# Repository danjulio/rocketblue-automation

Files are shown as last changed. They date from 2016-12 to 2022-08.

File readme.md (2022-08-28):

## Rocket Blue Automation

This directory contains information for Rocket Blue Automation projects.

### Solar Pi Platter

The [Solar Pi Platter](https://www.danjuliodesigns.com/products/solar_pi_platter.html) is a sophisticated expansion board for the Raspberry Pi Zero and Pi Zero 2 W single-board computers first introduced on [kickstarter](https://www.kickstarter.com/projects/1647124460/solar-pi-platter) in 2016.

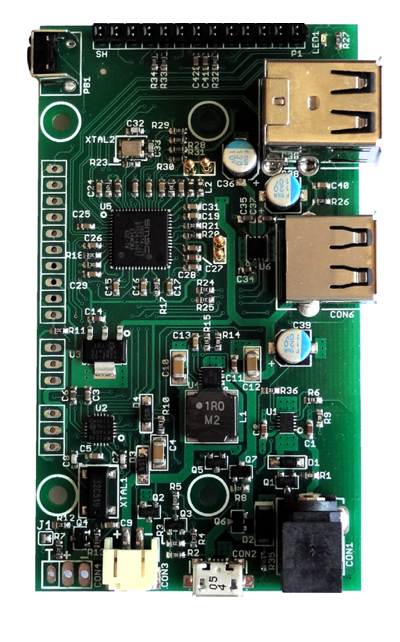
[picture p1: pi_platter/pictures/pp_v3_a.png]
Solar Pi Platter


The board can be purchased on [tindie] (https://www.tindie.com/products/globoy/solar-pi-platter/).

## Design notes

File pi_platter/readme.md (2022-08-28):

## Documentation

This directory contains supporting material for the [Solar Pi Platter](https://www.danjuliodesigns.com/products/solar_pi_platter.html) including documentation, utility software and example projects.

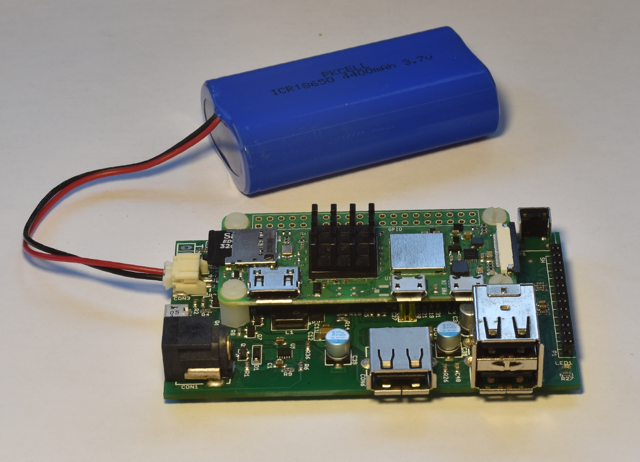
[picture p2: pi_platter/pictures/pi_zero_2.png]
Pi Zero 2 W


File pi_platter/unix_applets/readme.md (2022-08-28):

## Documentation

This directory contains Raspbian utility software for the Solar Pi Platter.

### talkpp
talkpp is a utility program to simplify communicating with the Solar Pi Platter.  It provides a simple command-line interface to allow the user to directly (or via scripts) send commands to the board and to easily manage the Real Time Clock.  

Starting with version 0.5 it can communicate with the Solar Pi Platter via either the pseudo-tty /dev/pi-platter if the ppd daemon is running or the actual hardware serial device associated with the board if ppd is not running.  It uses udev to automatically find the correct serial device for the board, independent of other USB serial devices.

Both the source and a binary compiled under Raspbian Jessie are included.  The binary can simply be downloaded and installed in /usr/local/bin.  The source is easily compiled in the directory containing the source file.

    sudo apt-get update
    sudo apt-get install libudev-dev
    gcc -o talkpp talkpp.c -ludev
    sudo mv talkpp /usr/local/bin

talkpp takes the following arguments:

    talkpp [-c <command string>]

          [-s] [-t] [-f]

          [-a <alarm timespec>] [-d <delta seconds>] [-w]

          [-u | -h]

    -c <command string> : send the command string.  Command strings without an "=" character cause the utility to echo back a response.

    -s : Set the Device RTC with the current system clock
 
    -t : Get the time from the Device RTC and display it in a form useful to pass to "date" to set the system clock ("+%m%d%H%M%Y.%S")

    -f : Get the time from the Device RTC and display it in a readable form.

    -a <alarm timespec> : Set the Device wakeup value (does not enable the alarm).  <alarm timespec> is the alarm time in date time format ("+%m%d%H%M%Y.%S")

    -d <delta seconds> : Set the Device wakeup to <delta seconds> past the current Device RTC time value (does not enable the alarm)

    -w : Display the wakeup value in a readable form.

    -u, -h : Usage (and optional help)

Example command to Solar Pi Platter: `talkpp -c B`

Setting the Solar Pi Platter RTC from the Pi's RTC: `talkpp -s`

Setting the Pi's RTC from the Solar Pi Platter (using BASH): `sudo date $(talkpp -t)`

talkpp will echo responses from the Solar Pi Platter to stdout.  It will also echo the last warnings or error messages that has been sent.

### ppd
ppd is a daemon for the Solar Pi Platter.  It provides two main functions.  It will execute a controlled shutdown if the Solar Pi Platter detects a critical battery voltage (and will power-down the entire system after [default] 30 seconds).  Since it opens the serial port associated with the Solar Pi Platter it also provides one or two mechanisms for other applications to communicate with the Solar Pi Platter.  It creates a pseudo-tty device named /dev/pi-platter which can be used just like the hardware serial port.  It also, optionally, can create a TCP port for applications like telnet to connect to.  

It is important that software not open the hardware serial port, /dev/ttyACM<n>, when ppd is running since it is using the port.

ppd takes the following command line arguments:

    -d : Run as a daemon program (disconnecting from normal IO, etc).  ppd can be run as a traditional process without this argument.

    -p netport : Enable a TCP socket connection on the specified port.  This is required to enable socket communication with ppd.  Exclude this line to only enable /dev/pi-platter as a mechanism to communicate with the Solar Pi Platter.

    -m max-connections : Specify the maximum number of socket connections that can be made to the port specified with -p.  The default is 1.

    -o seconds : Configure Pi Platter to shut off power after the specified period upon receipt of SIGTERM.

    -r : Enable auto-restart on charge (set the Pi Platter "C7=1") after critical battery shutdown.

    -x debuglevel : Set the debug level (ppd uses the system logging facility.  0 is default (only log start-up).  Values of 1 - 3 include progressively more information.

    -h : Display usage and command line options.

There are many ways to start a daemon, for example a configuration file in / or a script in /etc/init.d.  A very easy way to start it is to include it in /etc/rc.local.  For example, add the following before the "exit 0" at the end of /etc/rc.local (assuming you have placed the ppd executable in /usr/local/bin).

    # Start the Pi Platter Daemon
    /usr/local/bin/ppd -p 23000 -r -d &

This starts ppd with socket communication available on port 23000 and auto-restart in the event of a critical battery shutdown.

Both the source and a binary compiled under Raspbian Jessie are included.  The binary can simply be downloaded and installed in /usr/local/bin.  The source is easily compiled in the directory containing the source file.

    sudo apt-get update
    sudo apt-get install libudev-dev
    gcc -o ppd ppd.c -ludev
    sudo mv ppd /usr/local/bin

### pp\_power\_mon
pp\_power\_mon is a Desktop widget designed to display the Solar Pi Platter voltage and charge status as well as provide control over the two switchable USB ports.

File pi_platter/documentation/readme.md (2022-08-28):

## Documentation

This directory contains documentation for the Solar Pi Platter.

1. instructions\_v1_0.pdf - A quick summary of board operation, command set and configuration items.
2. solar\_pi_platter.pdf - The User Manual.
3. solar\_pi\_platter_schem.pdf - The board schematic.
4. USB\_expansion_example.png - An image showing how to use the board with a computer other than the Raspberry Pi Zero using a USB cable to supply both power and data.

### Questions?

Contact the author - dan@danjuliodesigns.com

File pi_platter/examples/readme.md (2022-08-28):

## Examples

 1. Porta-Pi - Using the Pi Platter, along with a high resolution 1024x600 pixel HDMI monitor to build a touchscreen computer with soft power off.
 2. motioneyeos - Using the Pi Platter to provide battery backup and pan/tilt functionality to the motioneyeos distribution.
 3. pi_car - The original demo created during development of the Pi Platter using it to provide power and motor control to a wifi-controlled robotic car with vision.
 4. solar_timelapse - A solar powered timelapse camera using the solar charging capability of the Pi Platter along with RTC-controlled wake-up for a raspberry pi camera.

 The ```nature_cam.sh``` script is a simple demonstration script that can be included in a camera like the solar_timelapse along with a servo to take pictures in multiple directions.
 
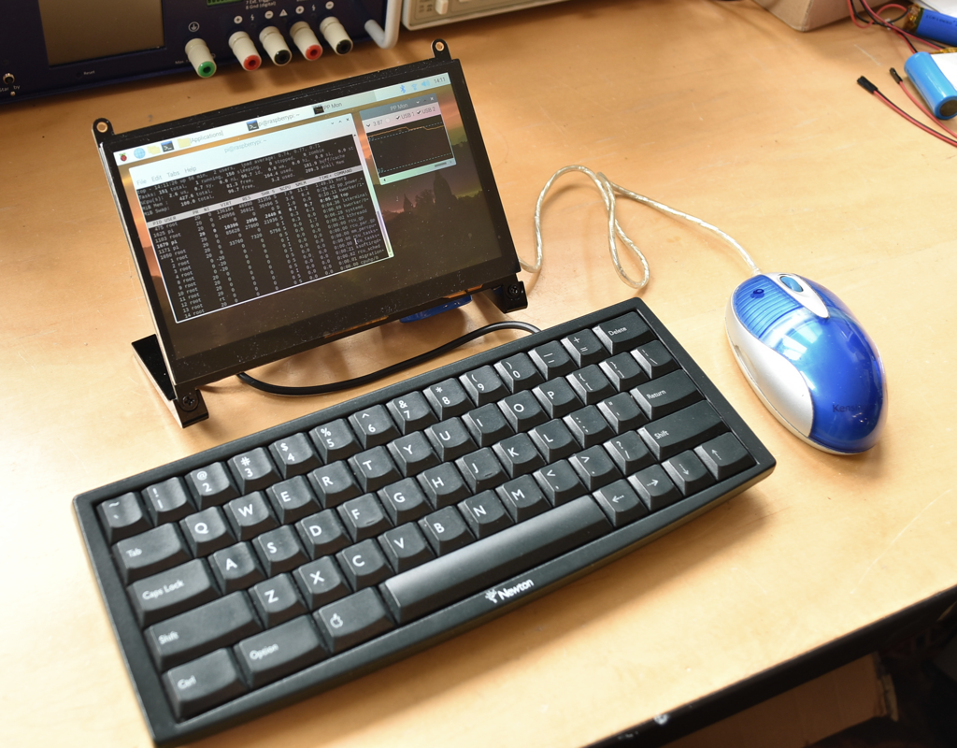
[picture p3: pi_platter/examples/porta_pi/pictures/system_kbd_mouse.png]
Porta-Pi

 
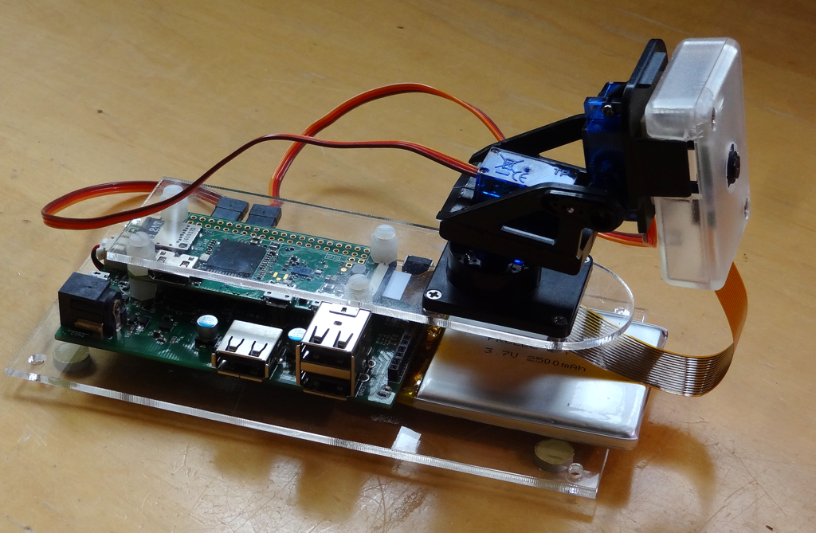
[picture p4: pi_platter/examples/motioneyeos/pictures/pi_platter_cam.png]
Motioneyeos camera


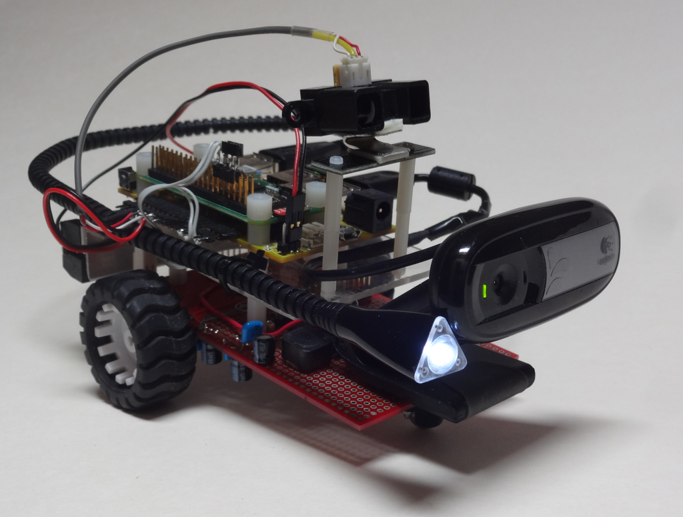
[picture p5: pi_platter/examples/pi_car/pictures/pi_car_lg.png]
Pi Car


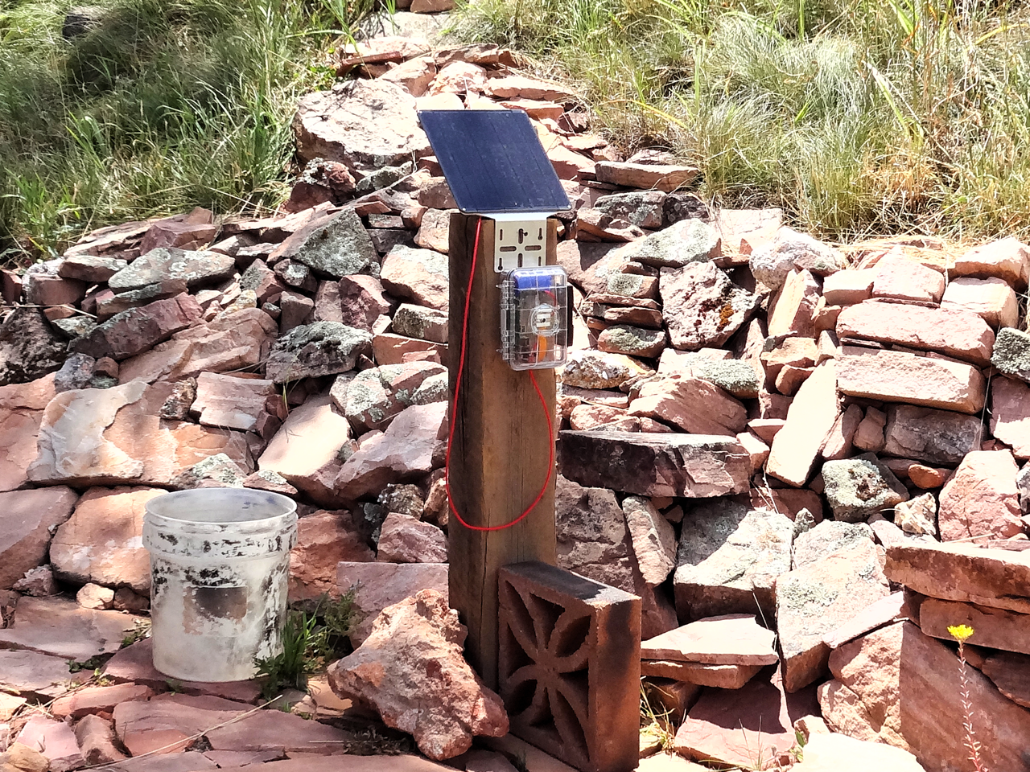
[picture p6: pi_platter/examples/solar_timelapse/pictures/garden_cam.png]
Timelapse Camera


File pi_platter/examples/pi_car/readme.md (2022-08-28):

## Documentation

This directory contains the components used for the Pi Car designed as an example during the kickstarter campaign.  It probably can't be used as-is but may give some ideas.

Pi Car

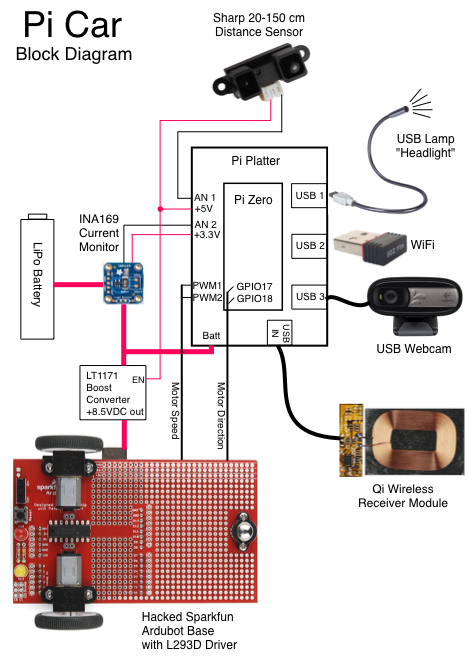
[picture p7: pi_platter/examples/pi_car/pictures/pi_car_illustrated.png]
Pi Car Block Diagram


### Motor Control

The Pi Car was built on an old Sparkfun Ardubot base.  The Ardubot was designed to be controlled by an Arduino with only forward/reverse control at a fixed speed but contained a prototyping area.  It used a L293D driver with the Enable input tied high.  I modified the board so the Solar Pi Platter PWM signals drove the Enable input for speed control.  A pair of NPN transistor inverters allowed Pi GPIO signals to control motor direction.  The high PWM frequency is used for smooth motor control.

A LT1171 boost converter was used to step up the battery voltage to approximately 8.5 volts to provide power for the motors.

### Video

A Logitech USB camera coupled with mjpg-streamer handled up to 15 fps at 320x240 pixels for reasonable video streaming.  mjpg-streamer setup is not described here but is fairly straight forward.

A Sharp distance sensor was mounted above the camera and connected to a Solar Pi Platter analog input with Vref set to 4.096 volts.  A table in the control software maps the ADC value to distance.

### Other peripherals

A USB reading lamp made the perfect steampunk headlight and can be turned on and off using the Pi Platter’s per-port USB power switching.

An inexpensive INA169-based current sensor in series between the battery and the rest of the system and wired to the Pi Platter’s other analog input gives current draw.  The Pi Car idles at around 700 mA from a charged battery and can pull upwards of 1500-2000 mA when the motors are running and loaded.

Finally a Qi receiver module connects to the Pi Platter’s USB power input for wireless charging.

### Joystick control

An old analog joystick (2 10-kohm pots and a button) was connected to an Arduino Leonardo (DF Robot beetle) running a simple sketch that reported joystick and button information over a USB Serial link.

### Software

There are three software components.

1. pi\_car.c - This is the software running on the Raspberry Pi.  It uses a single TCP port for communication with the control software running on the control computer.  It requires [WiringPi](http://wiringpi.com/) to be installed (for access to the GPIO pins).
2. pi\_car\_tv - A [Xojo](https://www.xojo.com/) project that implements the main control program.  This project may be compiled for Windows, Mac OS X or Linux.  Xojo is a commercial product which requires a paid license to build a binary executable but the project can be compiled and run from within the IDE without any license.  Builds for several platforms are found here.
3. read\_joystick.ino - The arduino sketch reading the joystick.  Should be put in a folder called read\_joystick.

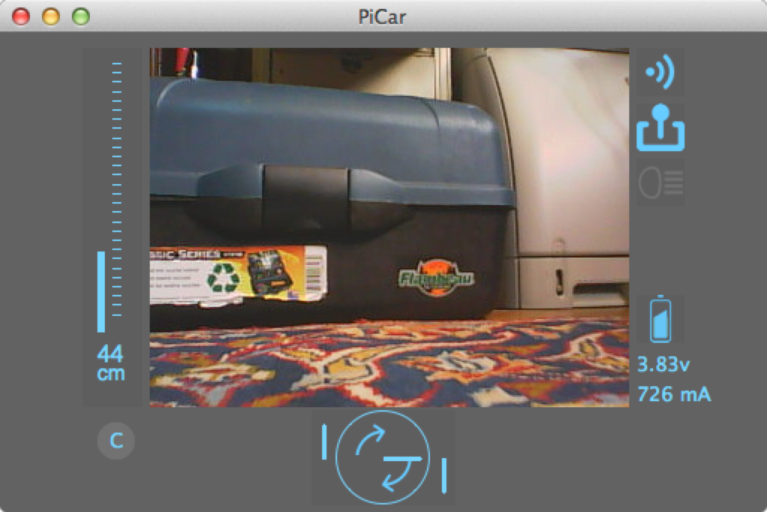
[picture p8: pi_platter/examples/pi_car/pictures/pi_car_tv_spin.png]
Pi Car Video


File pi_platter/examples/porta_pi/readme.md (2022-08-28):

## Porta-Pi
This directory contains the design for a 3D-printed baseplate and instructions for assembling a portable touchscreen based computer using the Raspberry Pi Zero 2 W that has higher resolution than the official 7" Pi LCD screen.  The Solar Pi Platter is used to provide power management, including soft power control, charging and switched USB expansion ports.  Features include

- 7" 1024x600 pixel capacitive touch LCD screen
- Stereo sound with built in speakers
- USB powered with 4400 mAHr battery for portable use
- Two power-switched USB ports
- Auto power-off after software shutdown using ```ppd``` utility.

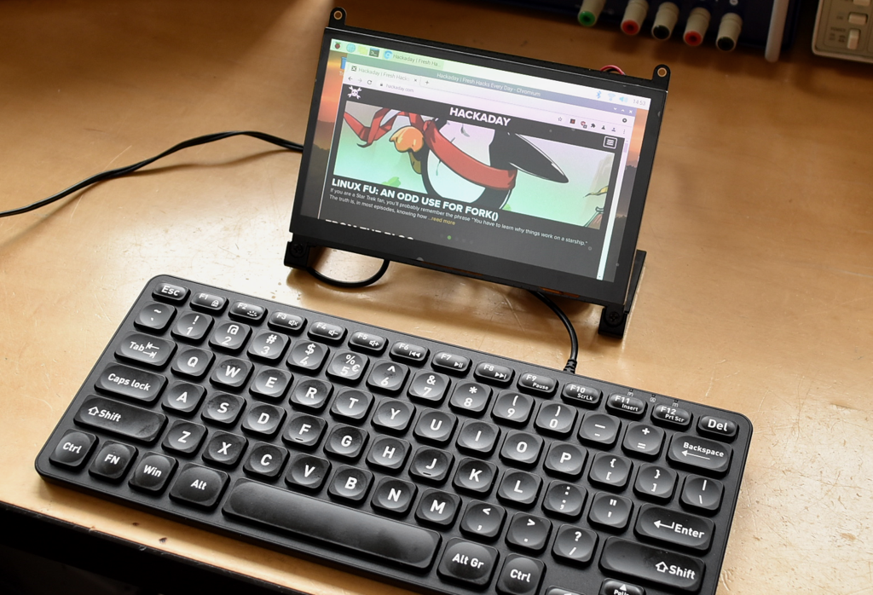
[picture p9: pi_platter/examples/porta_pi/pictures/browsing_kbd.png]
Browsing


### Parts

1. Solar Pi Platter ([tindie link] (https://www.tindie.com/products/globoy/solar-pi-platter/))
2. Raspberry Pi Zero 2 W
3. Norsmic 7" HDMI monitor ([Amazon link](https://www.amazon.com/gp/product/B09KB7XKB2))
4. 4400 mA 3.7V Li-Ion battery ([Adafruit link](https://www.adafruit.com/product/354)).  Be sure to use a battery with the Adafruit/Sparkfun style polarity 2mm JST connector.
5. Full-size to mini HDMI adapter (get the smallest adapter - not cable - you can find).
6. 4 4-40 3/8" nylon stand-offs (the same stand-offs that come with the Solar Pi Platter).
7. 2 165x2.5mm (6.5x0.1") zip ties.
8. 3D printed base plate (using STL files found here).

In case the Amazon link no longer works, look for a monitor like the following.  You will use the short USB cable and flex circuit HDMI cable.  The included Power Adapter and MicroUSB cable can be used to power the Porta-Pi.

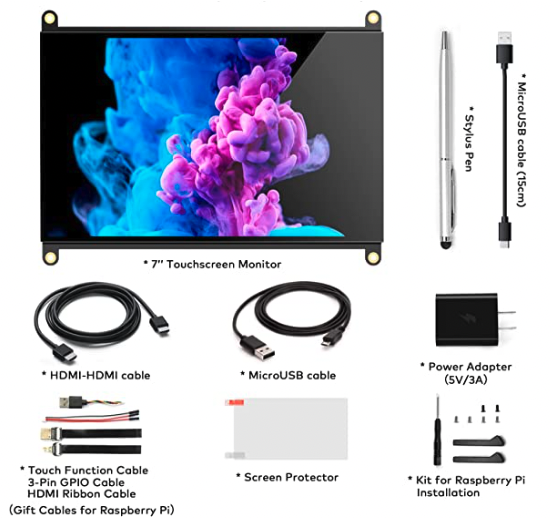
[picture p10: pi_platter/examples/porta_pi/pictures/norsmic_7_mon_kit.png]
Norsmic 7" Monitor


### Assembly
#### Base Plate
Slice and 3D print the ```mount_plate.stl``` file from the ```baseplate``` directory here.

Install the four extra stand-offs using the nuts from the Solar Pi Platter and the two zip ties (don't close them fully yet).

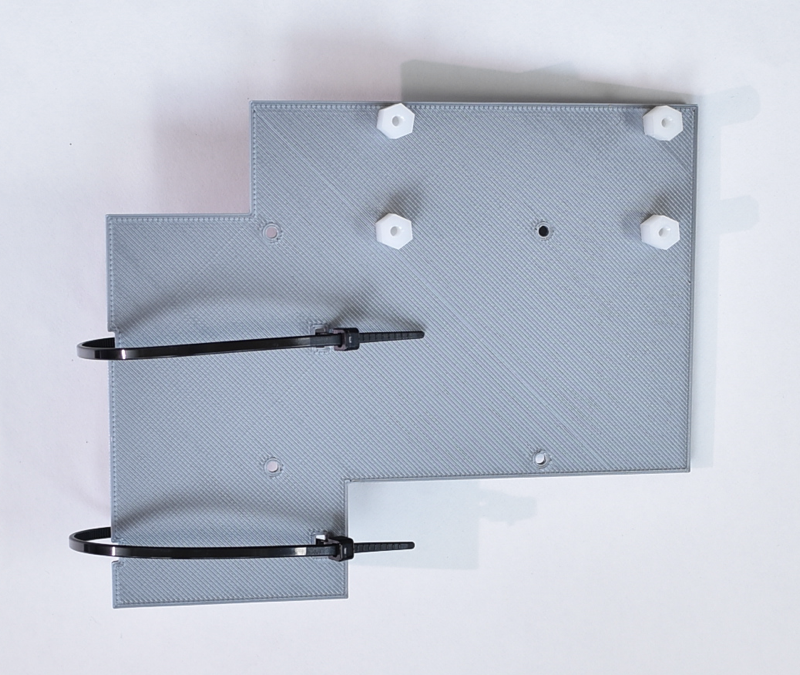
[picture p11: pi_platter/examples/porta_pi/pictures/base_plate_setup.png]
Base Plate Setup


#### Add USB and HDMI cables to LCD module
The Norsmic LCD screen comes with several cables including a short USB cable and a short flat HDMI cable.  Connect those to the monitor as shown below.  I used some tape to ensure the flat cable was secure.

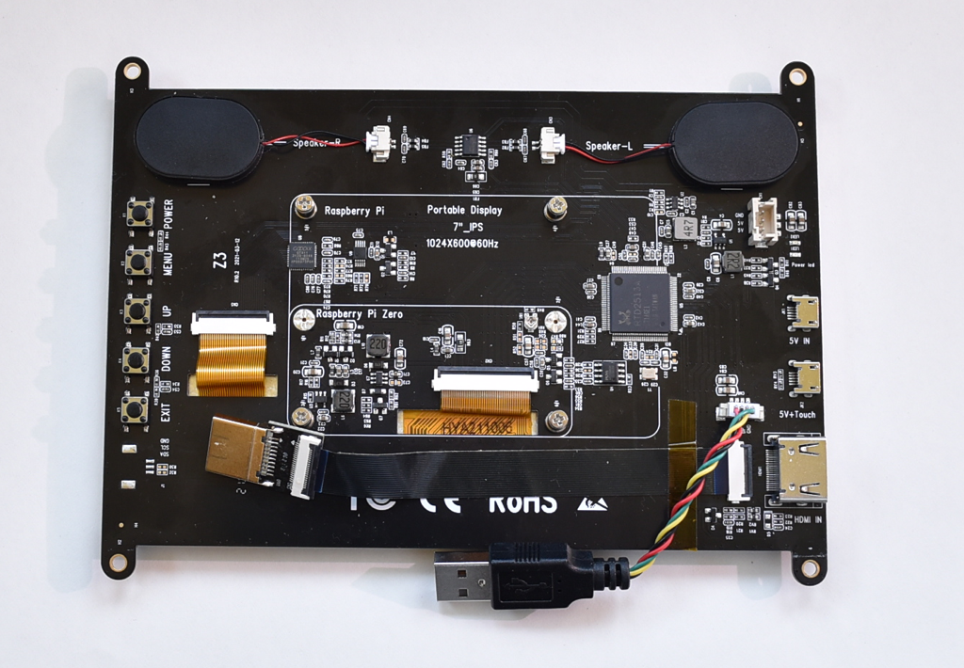
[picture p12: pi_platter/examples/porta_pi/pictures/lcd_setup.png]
LCD Screen Setup


#### Mount Base Plate
Attach the assembled Base Plate to the Raspberry Pi standoffs on the back of the monitor using the four metal screws that came with it.

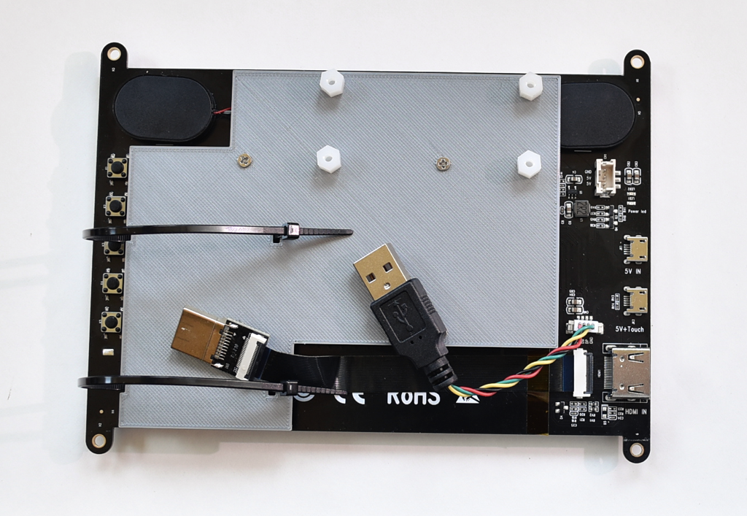
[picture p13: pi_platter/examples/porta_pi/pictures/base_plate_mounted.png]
Mounted Base Plate


#### Mount the Pi Platter and Battery
Attach the Pi Platter to the Base Plate using the four stand-offs that came with it.   Plug the USB cable into the single (un-switched Pi Platter USB port).  Also mount the battery to the Base Plate as shown below and tighten the zip ties to hold it in place.  Cut off the extra zip tie material.

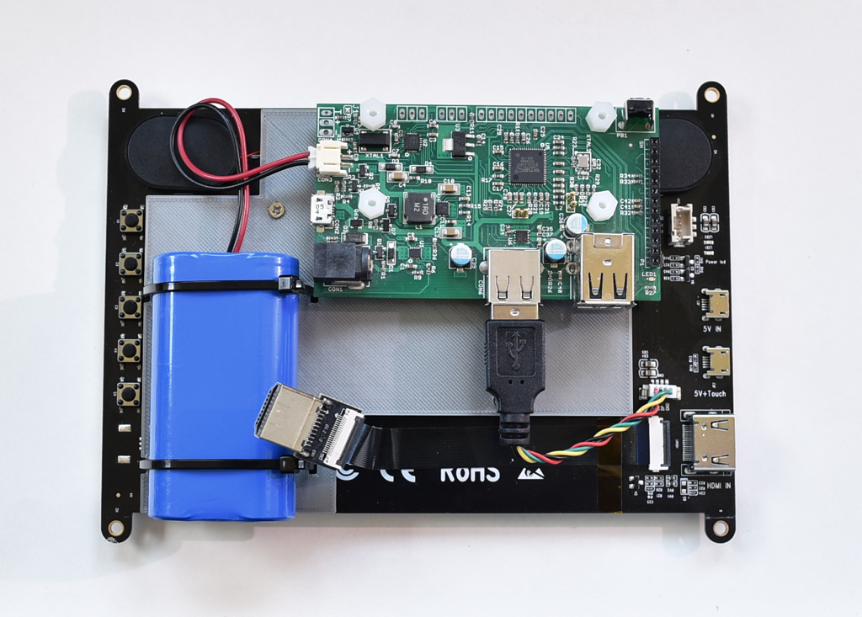
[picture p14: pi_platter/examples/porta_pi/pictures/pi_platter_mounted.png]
Mounted Pi Platter


#### Mount the Raspberry Pi Zero 2 W

Attach the Pi Zero to the Pi Platter using the four nylon screws that came with the Pi Platter.  Plug the HDMI cable into the Pi's mini-HDMI port using the HDMI to Mini HDMI adapter plug.

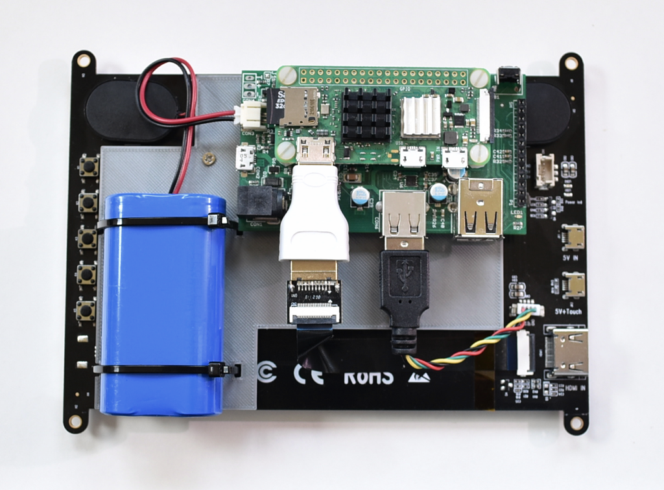
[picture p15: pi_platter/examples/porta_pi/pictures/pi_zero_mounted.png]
Mounted Pi


Congratulations, the hardware is assembled.  You can use the mounted provided in the monitor kit or you can assembled the completed unit into your own enclosure using the screw mounts on the top and bottom of the monitor PCB.

#### Note about power
The ideal power source for this system is a 2.5A 5.1V Micro-USB power supply such as the official Raspberry Pi supply.  The slightly higher supply voltage allows the Pi Platter to both power the system and charge the battery with its maximum 750 mA charge rate.

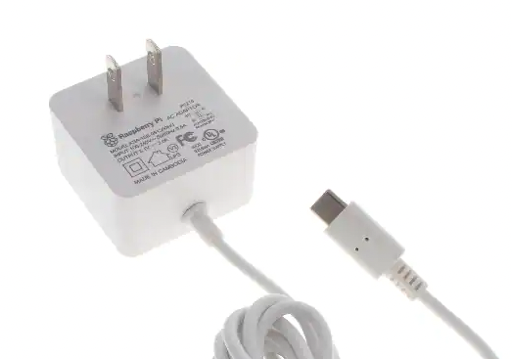
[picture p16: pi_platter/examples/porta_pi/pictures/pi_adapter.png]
Official Pi Adapter


The adapter supplied by Norsmic or other adapters with > 2.5A can also be used.

WARNING: Only plug the USB cable into the Pi Platter Micro-USB port.  Do not connect anything to either Pi Micro-USB ports.  Doing so may damage the Pi Platter.

You can even use the solar panel input on the Pi Platter to charge the system from sunlight.  However that input won't be able to keep both the battery charged and system powered so it would be most useful in a situation where you charge the system using solar power and then run it for a while from the battery.

### Software Setup
#### Load Raspbian
Load a 32-bit Raspbian distribution onto a Micro-SD card and install it in the Raspberry Pi.  Power the Pi Platter with the USB adapter.  Turn the system on by pressing the Pi Platter power button.  You will see the green light turn on the Pi Platter followed by the Raspberry Pi booting.

#### Load and configure the Pi Platter utilities
Install the ```ppd``` utility program (found in this repository or from my website), for example in ```/usr/local/bin```.  Add the following line  to the ```/etc/rc.local``` file.

	/usr/local/bin/ppd -p 23000 -o 30 -r -d &

This will configure the utility as a daemon that watches for the SIGTERM signal and uses that to power off the system 30 seconds later.  This signal is sent when you select shutdown from the GUI or execute ```shutdown now``` from the command line.

You may also install ```ppp_power_mon``` to add a desktop widget displaying the current battery level and charge status, as well as providing controls to switch on and off the other two USB ports on the Pi Platter.

### Operation
Switch the system on by pressing the power button on the Pi Platter.

Switch the system off by selecting ```Logoff->Shutdown``` from the Start Menu or typing ```sudo shutdown now``` in a terminal.

The monitor should automatically power on when the Pi video starts.  You use the buttons on the monitor PCB to control brightness and volume.

### Questions?

Contact the author - dan@danjuliodesigns.com

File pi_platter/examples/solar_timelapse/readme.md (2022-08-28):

## Documentation

This directory contains the script for the solar powered time-lapse camera documented at [my website](https://www.danjuliodesigns.com/products/pi_platter_timelapse.html).

The script controls taking a picture, scheduling the next wake-up time for the system and then executing a controlled shutdown and power-down.

It also monitors a switch attached to the Solar Pi Platter A1 input to allow the user to power-up the system without the time-lapse camera functionality (for example, to off-load photos).

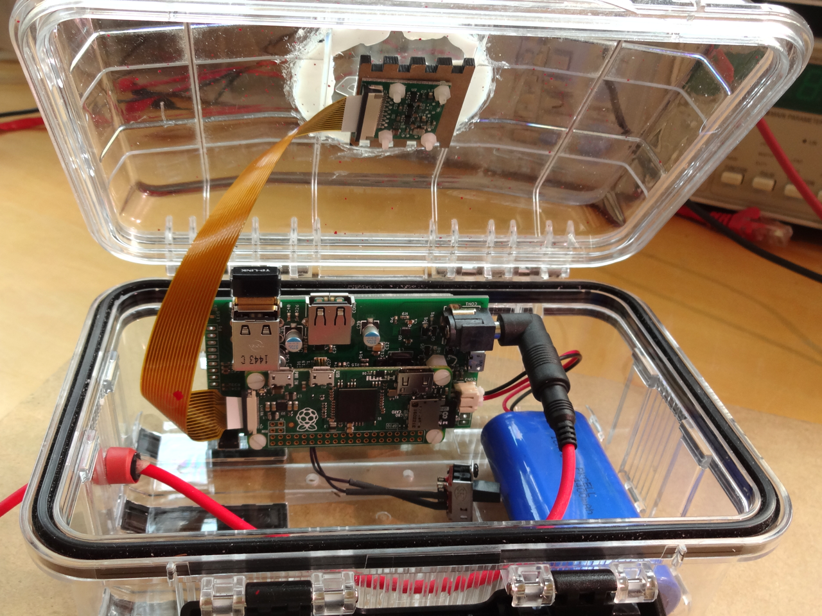
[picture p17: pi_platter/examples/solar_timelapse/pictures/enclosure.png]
Timelapse Camera


### Configuration

Install and configure an operating system.  I use [DietPi](http://dietpi.com).  Install any necessary additional software such as ssh and configure WiFi if desired.

Install talkpp and the powerdown script in /usr/local/bin.

Install the timelapse.sh script in /usr/local/bin.

Create the picture repository at /usr/local/pictures: sudo mkdir /usr/local/pictures.

Edit /etc/rc.local and add the lines

	# Start the photography script
	/usr/local/bin/timelapse.sh &

Set the Solar Pi Platter RTC from the Pi (after it's clock as been set) using the command

	talkpp -s

### Hardware

A switch with a 10k-ohm pull-up resistor is connected to the Pi Platter A1 input.  The pull-up is connected between A1 and 3.3V so that A1 is high when the switch is open. The switch is connected between A1 and GND so that A1 is low when the switch is closed.

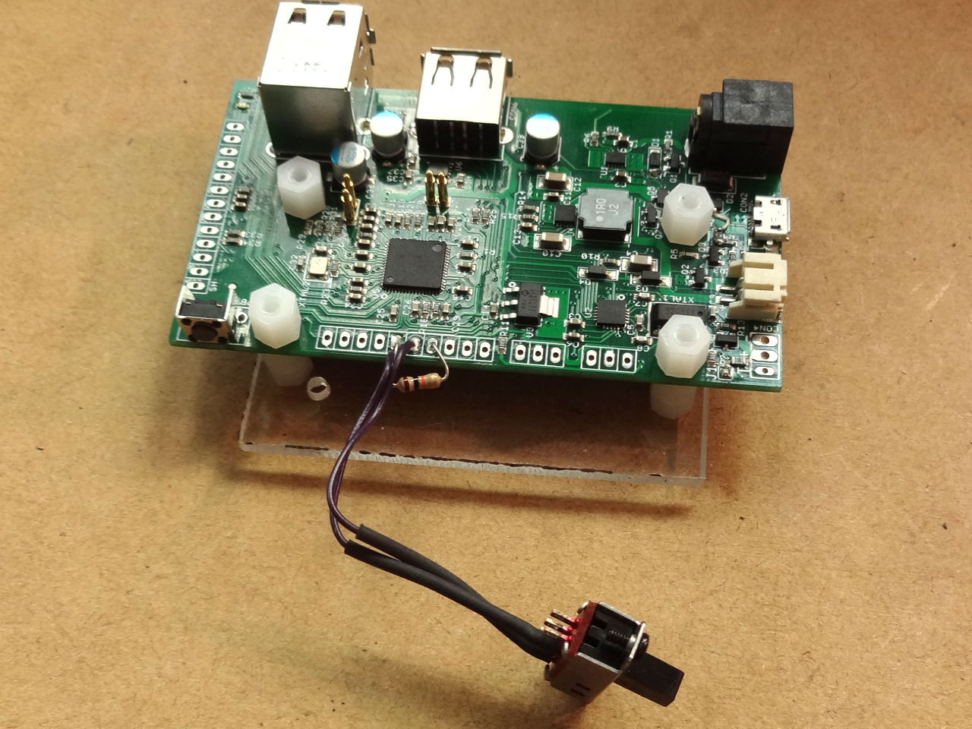
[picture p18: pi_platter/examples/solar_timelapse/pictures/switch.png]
Switch Wiring


Power is supplied using a 6V 9W solar panel such as this one from [voltaic](https://voltaicsystems.com/9-watt-panel/).

### Operation

Open the switch and power-up the Pi Platter.  It will take the first photograph, schedule the next photograph and then power down.

Close the switch before powering up to configure the device into offload mode.

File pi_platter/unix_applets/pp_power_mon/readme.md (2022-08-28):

## pp\_power\_mon

This directory contains the code for the pp\_power\_mon GUI program.  This utility displays the Pi Platter battery voltage and charge status and allows control of the switchable USB port power in a little applet in a small window on the Raspberry Pi desktop.

The utility is written using the [Xojo](https://www.xojo.com) development environment and compiled for 32-bit ARM 7 linux (such as found on the Raspberry Pi Zero 2 W but not the original Raspberry Pi Zero).  It should run on other ARM 7 linux computers with hardware floating point support.  Both the Xojo source and compiled binary are found here.

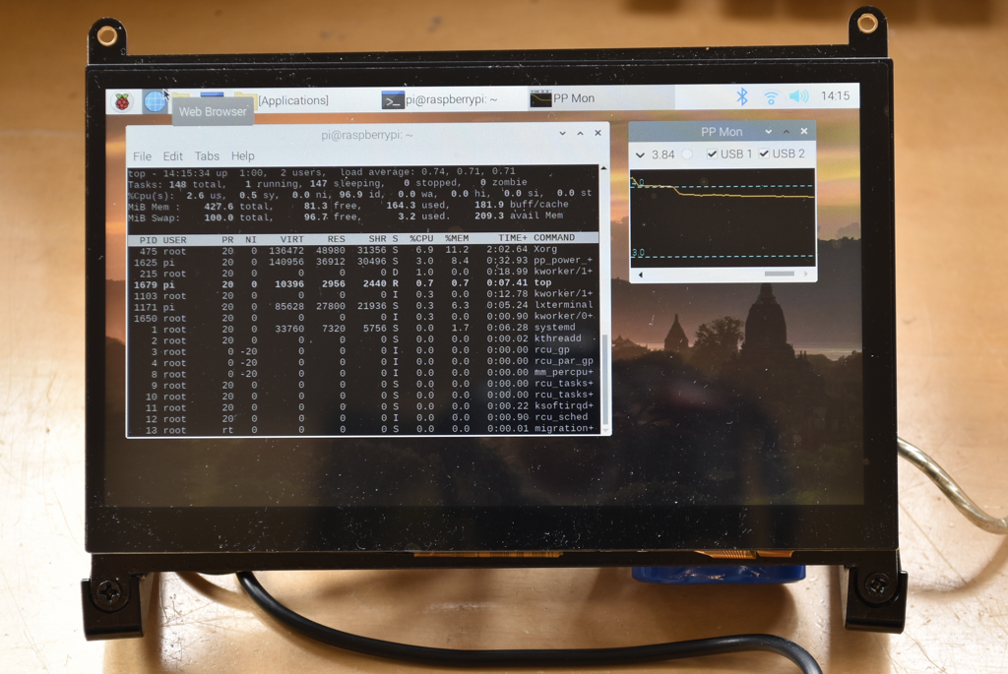
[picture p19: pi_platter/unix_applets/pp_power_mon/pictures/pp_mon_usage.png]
Utility on Desktop


### Installation
Copy the ```ppp_power_mon.zip``` file found at the following locations to your Pi.

1. In this repository in the ```xojo/Builds - pp_power_mon/Linux ARM/``` directory
2. From the download section on the Solar Pi Platter page at my [website](https://www.danjuliodesigns.com/products/solar_pi_platter.html).

Unzip in a known location such as Applications in the Pi user's home directory.

	unzip ppp_power_mon.zip
	
The executable ```ppp_power_mon```, along with supporting libraries, will be found in the unpacked directory.

	pi@raspberrypi:~/Applications $ ls pp_power_mon/
	pp_power_mon  'pp_power_mon Libs'  'pp_power_mon Resources'

Ensure the binary is executable.

	pi@raspberrypi:~/Applications $ chmod +x pp_power_mon/pp_power_mon

### Running and Operation

Execute the utility from a shell that has the desktop environment configured (e.g. a terminal window).

	pi@raspberrypi:~/Applications $ ./pp_power_mon/pp_power_mon &

The utility should start in a condensed format showing the battery voltage, charge status and USB power controls.

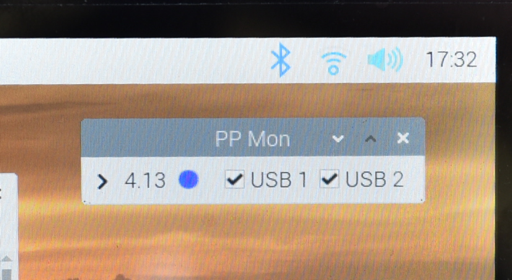
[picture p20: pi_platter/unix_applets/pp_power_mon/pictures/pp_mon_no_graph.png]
Condensed Utility


The status indicator to the right of the battery voltage displays the following information via its color.

- Battery Charging : Green
- Battery Low : Red
- Power from USB (not charging) : Blue
- Normal battery operation : White

Clicking the disclosure arrow to the left of the battery voltage displays the battery graph (updated every second).  The following picture shows the battery voltage after charging commenced.

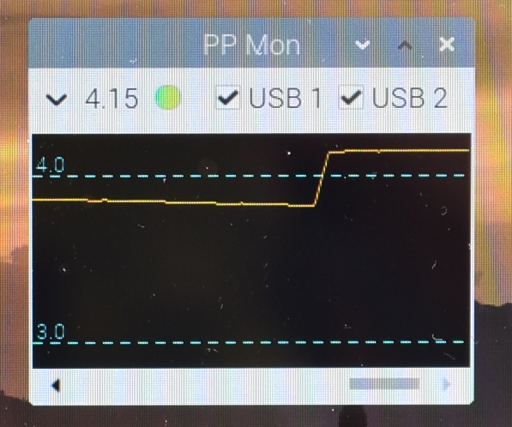
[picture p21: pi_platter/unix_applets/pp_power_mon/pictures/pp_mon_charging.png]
Utility with Graph


The checkboxes are used to turn power on and off to the two switchable USB ports on the Solar Pi Platter.  Just be sure your mouse isn't plugged in to the port you turn off... 

### Note
This program won't run on the original Raspberry Pi Zero or Raspberry Pi Zero W because they lack the hard floating point that the Xojo binary requires.

### Questions?

Contact the author - dan@danjuliodesigns.com

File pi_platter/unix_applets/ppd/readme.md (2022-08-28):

## ppd

This directory contains the code for the ppd daemon.

ppd is a daemon program designed to run on a Raspberry Pi (or other linux computer).  It allows the system to execute a controlled shutdown in the case of a critically low battery voltage (that has triggered the Solar Pi Platter to start a count-down to powering down the entire system).  This is important to protect the Raspberry Pi's SD-card filesystem from corruption that can occur when power is removed from a running system.  It does this by connecting to the hardware serial port associated with the Solar Pi Platter (like talkpp, it uses udev to figure this out) and looks for the WARN string sent the Solar Pi Platter for critical battery detection.  Since it "commandeers" the hardware serial port, it also provides additional mechanisms for user application code to communicate with the Solar Pi Platter.  It always creates the pseudo-tty "/dev/pi-platter" which can be treated like a serial port connection.  It can optionally also create a TCP socket for network communication with the Solar Pi Platter.

It uses udev to be able to idenfity which hardware serial device belongs to the Solar Pi Platter (via the USB VID, PID and product strings).

###Building

A prebuilt binary is included here but building is very easy:

    gcc -o ppd ppd.c -ludev

The compiled binary should be copied to /usr/local/bin.

    sudo mv ppd /usr/local/bin

You may have to set appropriate permissions (you will have to do this if you just copy the
prebuilt binary from git to /usr/local/bin).

    sudo chmod 775 /usr/local/bin/ppd

libudev-dev must be installed:

    sudo apt-get update
    sudo apt-get install libudev-dev

###Usage

ppd should be started as a daemon at start-up.  The easiest way to do this is to include somethine like the following in /etc/rc.local.

    # Start the Pi Platter Daemon
    /usr/local/bin/ppd -p 23000 -r -d &

It is also possible to create a conf file in /etc/init or a startup script in /etc/init.d.

####Command line options

ppd takes the following command line arguments:

    -d : Run as a daemon program (disconnecting from normal IO, etc).  ppd can be run as a traditional process without this argument.

    -p netport : Enable a TCP socket connection on the specified port.  This is required to enable socket communication with ppd.  Exclude this line to only enable /dev/pi-platter as a mechanism to communicate with the Solar Pi Platter.

    -m max-connections : Specify the maximum number of socket connections that can be made to the port specified with -p.  The default is 1.
    
    -o seconds : Configure Pi Platter to shut off power after the specified period upon receipt of SIGTERM.

    -r : Enable auto-restart on charge (set the Pi Platter "C7=1") after critical battery shutdown.

    -x debuglevel : Set the debug level (ppd uses the system logging facility.  0 is default (only log start-up).  Values of 1 - 3 include progressively more information.

    -h : Display usage and command line options.

####telnet example

To connect to the TCP socket using telnet from some other computer:

    telnet <Raspberry Pi IP Address> 23000

Which should result in something like (user types "B" and then "S"):

    Trying <Raspberry Pi IP Address>...
    Connected to raspberrypi0.lan.
    Escape character is '^]'.
    B
    B=4.12
    S
    S=20

Note that opening the socket without additional precautions may be a security risk (anybody could telnet to your Pi and shut it down).  That's why ppd makes this an option.

####Soft shutdown
The ```-o``` option (introduced in version 0.2) configures the program to automatically power off the Pi a configurable number of seconds after receiving a SIGTERM signal.  SIGTERM is sent when the Pi has been commanded to shut down (for example using the GUI or ```shutdown``` command).

Start the program as a daemon using this option with an argument of seconds longer than it takes for the Pi to execute a shutdown and the system will power off automatically.

	/usr/local/bin/ppd -p 23000 -o 30 -r -d &

Just be sure to use a SIGKILL to stop the daemon (```kill -9```) so that it doesn't misinterpret a ```kill`` you are sending it to stop it running for a system shutdown.

###Questions?

Contact the author @ dan@danjuliodesigns.com

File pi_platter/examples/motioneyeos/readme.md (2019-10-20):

# motioneyeos with battery backup, pan/tilt servos and status display
Calin Crisan's excellent [motioneyeos](https://github.com/ccrisan/motioneyeos) is a complete Linux distribution that turns the Raspberry Pi Zero into a highly functional wireless webcam.  He provides detailed instructions for installation and configuration; some are referenced here.  These instructions show how to use the Pi Platter to extend the capability of motioneyeos with battery backup, pan/tilt servos and a status information display.

Webcam

Installation is simple using the extension capabilities built-in to the motioneyeos distribution.  The Pan/Tilt controls as well as a status display showing battery and charging conditions show up in the web interface.

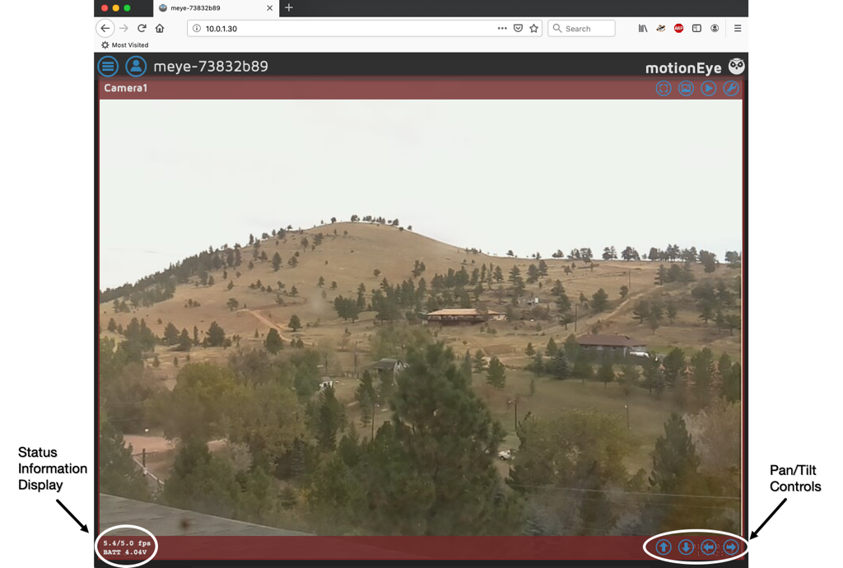
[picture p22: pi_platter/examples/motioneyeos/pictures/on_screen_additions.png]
On Screen Controls


Building this web cam consists of the following steps described in this readme.

1. Acquire necessary hardware
2. Assemble camera
3. Load the motioneyeos distribution onto the MicroSD card
4. Configure motioneyeos for your wifi and start it running
5. Add files from this repository to enable the new functions
6. Enjoy your new webcam

I encourage you to read the Pi Platter Manual found in the [documentation](https://github.com/danjulio/rocketblue-automation/tree/master/pi_platter/documentation) directory as well as the thorough documentation in the [motioneyeos wiki](https://github.com/ccrisan/motioneyeos/wiki).

## Hardware components
I built my unit using components that I had on hand.  You can certainly substitute some components like the backup battery and pan/tilt assembly.

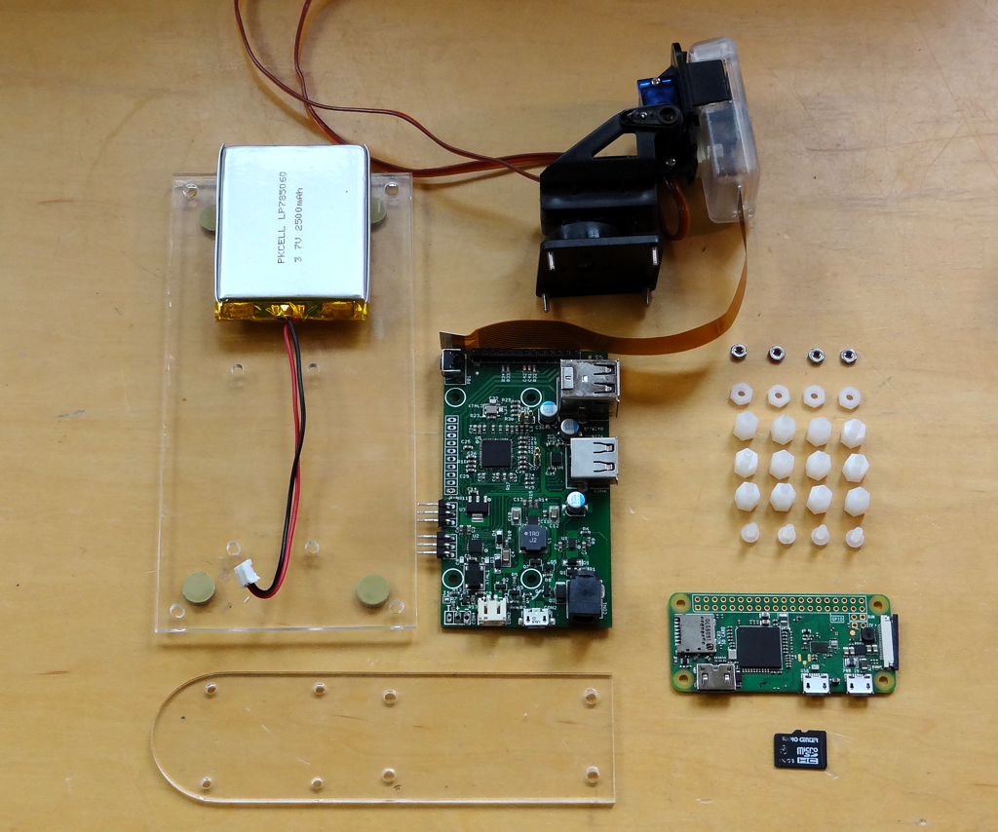
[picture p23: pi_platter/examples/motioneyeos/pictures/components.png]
Components


1. Raspberry Pi Zero W with Pi Camera and cable.  Available from [Adafruit](https://www.adafruit.com/product/3400) as well as other distributors.
2. Pan/Tilt assembly with 5-6V servos.  There are a lot of these available.  I used the pan/tilt assembly from a [Pimoroni device](https://shop.pimoroni.com/products/pan-tilt-hat).  The main thing to note is that you should use smaller (lower-current) servos.  These operate better on 5V.  I enclosed my camera in a small plastic box but most pan/tilt assemblies have a way to directly attach the camera.
3. 8 GB or larger Micro-SD card.  Available everywhere but I often buy industrial rated cards like the [Sandisk SDSDQAF3-008G-XI](https://www.mouser.com/ProductDetail/SanDisk/SDSDQAF3-008G-XI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).
4. [Solar Pi Platter](https://www.tindie.com/products/globoy/solar-pi-platter/) available on tindie.
5. 2000-6000 mA 3.7 volt LiPo battery.  I used a [2500 mA battery from Adafruit](https://www.adafruit.com/product/328) that should provide at least 2-3 hours of run-time.
6. [5.1 - 5.25 volt 2A USB Power supply](https://www.amazon.com/Argon-Raspberry-Listed-Power-Supply/dp/B07MC7B9X3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) with USB Micro-B connector.  The wiring in many USB adaptors is pretty thin which leads to a voltage drop at the input of the Pi Platter that may cause it to reduce charging current unnecessarily.
7. Fastening hardware.  I used the same nylon 4-40 0.25 inch tall nylon stand-offs and nuts/screws as are used to fasten the Pi Zero to the Pi Platter.  Search for the following part numbers on Mouser: 561-MF440-25, 561-G440, and 561-P440.25.
8. Two 3-pin right-angle 0.1 inch headers for the servo connections.  Alternatively you can solder the servo wires directly to the Pi Platter PWM outputs.
9. Enclosure.  I laser-cut a two piece assembly for this example but you may want a different type of enclosure depending on your application.  The files for my cut-outs may be found in the ```plastic_cutouts``` directory in this repository.

## Hardware assembly
Assembly is straight-forward.  The Pi Zero mounts on top of the Pi Platter using the included mounting hardware.  This assembly mounts in the enclosure in a stacked arrangement.

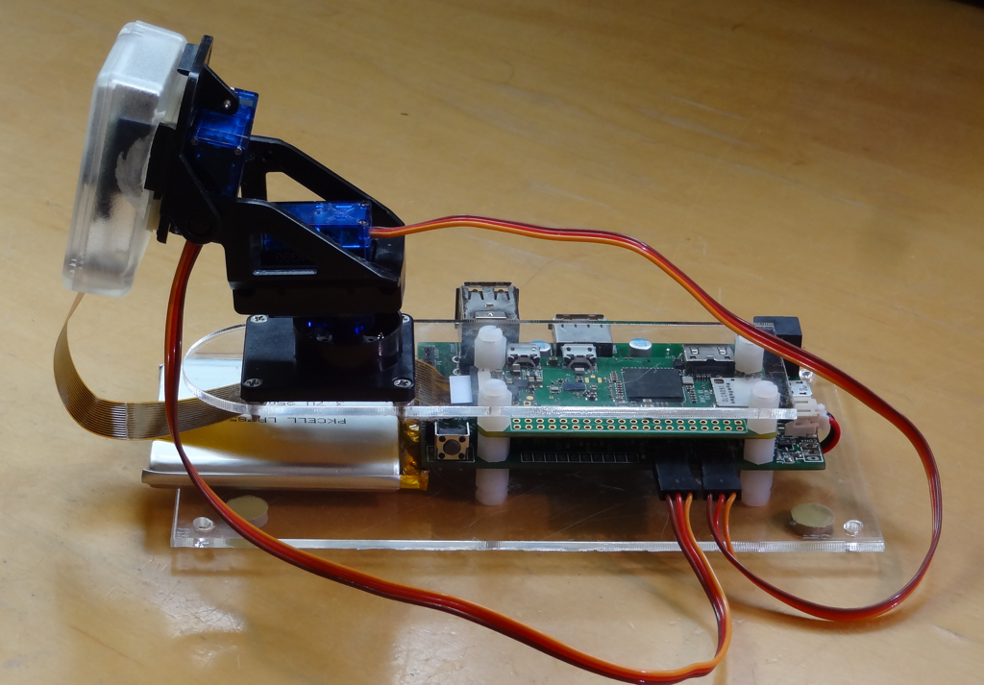
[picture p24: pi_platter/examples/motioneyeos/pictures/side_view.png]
Assembly Side View


I held the battery down with a piece of double-sided sticky tape.

Connections to the Pi Platter are made as shown in the following image. Check the servo connections to make sure they match.  Most servos I've seen use a Brown-Red-Orange cable for GND-5V-PWM.  

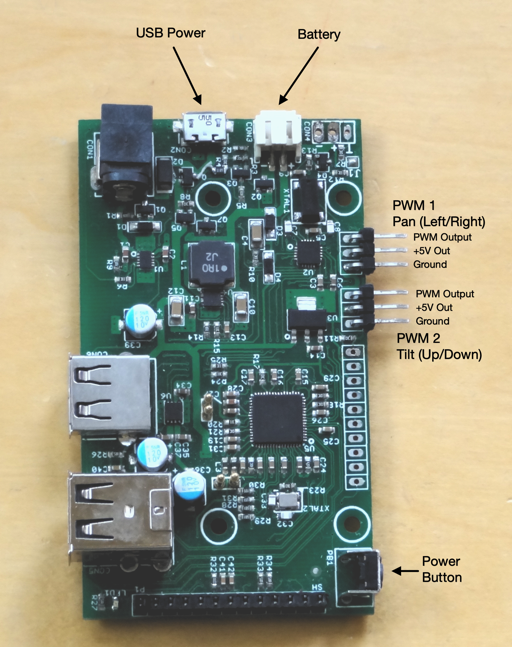
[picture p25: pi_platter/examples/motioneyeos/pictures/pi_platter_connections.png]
Pi Platter Connections


## motioneyeos installation
It may be helpful to attach a monitor and USB keyboard during installation.

### Install motioneyeos
1. Download motioneyeos for Raspberry PI (A, B, A+, B+, Compute Module, Zero and Zero W models) from the [github repository](https://github.com/ccrisan/motioneyeos/wiki/Supported-Devices).  I used version 20190427 and have kept a copy.  Contact me in case you run into a problem with the current version and I can arrange to transfer that to you.
2. Extract the image from the archive and [write the OS Image](https://github.com/ccrisan/motioneyeos/wiki/Installation) to your Micro-SD Card as described in the wiki.  
3. [Configure](https://github.com/ccrisan/motioneyeos/wiki/Wifi-Preconfiguration) the system to access your wifi as described in the wiki before attempting to boot.  You can also do this from the keyboard/monitor after booting if necessary.
4. [Configure](https://github.com/ccrisan/thingos/wiki/static_ip.conf) the system with a static IP address if you like.  Otherwise you'll have to use the keyboard/monitor or an external utility like Fing to determine the DHCP served IP address your Pi receives.

### Boot motioneyeos
Unmount the Micro-SD Card and put in the Raspberry Pi.  Connect the Pi Platter to the battery and USB Power supply.  Then power up the system by pressing the power button on the Pi Platter for two seconds until you see the green power LED light.  The initial boot may take a couple of minutes as motioneyeos configures itself.  You can see the progress if you have a monitor attached to the Pi.  After the system boots and motion starts you should be able to view your webcam by pointing your browser at the Pi's IP address.

## Pi Platter software installation
The motioneyeos distribution creates a partition, ```/data```, that is used to store persistent changes.  It is created during the first boot.  We manually put the additional files in this partition (```/data/etc```).

1. The pre-built ```talkpp``` binary found elsewhere in this [repository](https://github.com/danjulio/rocketblue-automation/tree/master/pi_platter/unix_applets/talkpp) is used by the scripts to communicate with the Pi Platter.
2. The five scripts found in the ```scripts``` directory here use the motioneyeos [Action Button](https://github.com/ccrisan/motioneyeos/wiki/Action-Buttons) capability to allow control of the servos and for displaying information from the Pi Platter in the web interface.

### Install files
The ```talkpp``` binary and five script files are easily copied to the  ```/data/etc``` directory using ```scp``` or via a USB Memory Stick.

#### Using scp

Download the files to your local computer and execute the following commands from a shell in the directory containing the files.  You would use a program like WinSCP on a Windows computer.  Put your Pi's IP address in the ```[IP Address]``` field.

```
	scp talkpp admin@[IP ADDRESS]:/data/etc
	scp *_1 admin@[IP ADDRESS]:/data/etc
```

Note that by default motioneyeos has no password.  You can and should add a password using the web interface.

#### Using a USB memory stick
1. Copy the files to a FAT-formatted USB memory stick on your computer.
2. Eject the memory stick and then plug it into one of the Pi Platter USB ports.  Motioneyeos will automatically mount it in the ```/data/media``` directory.
3. Log in to the Pi via ssh or using the keyboard/monitor and copy the files from the memory stick to the system.

```
	cp /data/media/sda1/talkpp /data/etc
	cp /data/media/sda1/*_1 /data/etc
```

### Ensure file permissions
Make sure that the files have the correct linux file permissions so that motioneyeos can execute them.  From a motioneyeos shell prompt, type the following.

```
	chmod 700 /data/etc/talkpp
	chmod 700 /data/etc/*_1
```

### Edit /data/etc/userinit.sh
The ```/data/etc/userinit.sh``` file allows motioneyeos to execute custom commands when it boots.  We use this facility to configure the Pi Platter to automatically restart the system in the case that AC power has failed and the system runs from battery until it is discharged and the Pi Platter shuts down power.

From a motioneyeos shell prompt, edit the ```/data/etc/userinit.sh``` file using an editor such as ```vi``` or ```nano```.  Add the following to the end of the file and save it.

```
	# Configure the Pi Platter to auto-restart on battery re-charge after shutdown
	/data/etc/talkpp -c C7=1 
```

## Restart and verify operation

Type ```reboot``` from a shell prompt or use the web interface to restart the system.  After it reboots you should be able to control the servos and view Pi Platter status via the motioneyeos web interface.  Clicking on the video image streaming from the camera should cause motioneyeos to add an overlay to the image with status information from the Pi Platter on the lower left and four pan/tilt buttons on the lower right.

Added Web Information

## Notes

### Servo range
The pan/tilt scripts have constants that set the minimum and maximum PWM values to send to the servos.  These were values I found worked for my system.  However you may end up needing to modify them if you find your servos hit the end of their motion range (they will make a grinding sound and take a lot of current as the motor tries to push the servo past its limit).  This can harm the servos as well as possibly draw so much current that the Pi Platter will shut down.

For example, the ```left_1``` script controls panning left.  It does this by increasing the PWM value written to the Pi Platter to control the pan servo on PWM 1.  The PWM values range from 0-255 but this script limits the maximum PWM value using the constant ```PWM_MAX``` (to 250 in my version).  You should decrease this value if you find the servo hitting the end of its range when panning left.  To change the maximum to 240, edit the ```left_1``` script and change the constant.

```
	# Maximum PWM value
	PWM_MAX=240
```

Likewise you would decrease the ```PWM_MAX``` constant in ```down_1``` and increase the ```PWM_MIN``` constant in ```right_1``` and ```up_1``` to further limit servo travel.

### Power notes
My system requires an average 430-450 mA from the USB power supply when running but not charging the battery.  It takes more current as the servos move and up to an additional 750 mA when charging the battery.  The USB Power adapter should be able to provide at least 2A of current.

The Pi Platter powers the system from the USB Power adapter when power is available on that input.  It uses a voltage threshold of approximately 4.7 volts to switch from USB power to the battery.  It also reduces the charge current to the battery as the USB input voltage drops.  Since many USB adapter cables use thin wires and the current draw by the system may exceed 1 A, the voltage seen by the Pi Platter may be significantly lower than the output of the USB adapter.  For this reason I recommend using an adapter that outputs 5.1 to 5.25 volts.

If you see ```AC PWR``` status display blinking on and off then it is likely that the USB voltage seen by the Pi Platter is too low and it is constantly switching between USB and battery power.

The system will draw over 700 mA from the battery when operating from it.  Battery capacities of 2000-6000 mA are a good match for this system depending on the amount of time it should be able to run on battery power alone.

### Shutting down power
The Pi Platter command ```C7=1``` executed in the modified ```userinit.sh``` file configures it to automatically restore power after a shutdown due to a low battery.  For this reason the system will also immediately power back on and reboot if you shut down power to the system by holding the Pi Platter power button for several seconds (because the battery voltage is above the restart threshold).  To shut down power, first log into the system and execute the following command to disable the auto-restart function before powering down the system using the Pi Platter power button.

```
	/data/etc/talkpp -c C7=0
```

## Optional Features

### Enable the Pi to act as a WiFi Access Point
The motioneyeos software may be configured to create its own network, acting as a WiFi access point.  This is useful for a remote time-lapse or security system located in an area without WiFi.  Configuring the system as a WiFi access point must be done after the initial installation/boot.  Detailed instructions can be found at [WiFi-Access-Point](https://github.com/ccrisan/motioneyeos/wiki/WiFi-Access-Point).

For some reason I don't understand enabling this mode disables ssh access so it's important to have finished the additional installation before performing these steps.

### Pi Platter RTC
The Pi Platter contains a battery-backed real-time clock that can be used to set the Pi's system clock for the cases that it is unable to access a network time server.

To set the Pi Platter RTC from the Pi's system clock (assuming it has the correct time and date):

```
	/data/etc/talkpp -s
```

To set the Pi's system clock from the Pi Platter RTC:

```
	date $(/data/etc/talkpp -t)
```

This command may be included in the ```userinit.sh``` file.

### Temperature Measurement using Pi Platter analog input
The Pi Platter includes two analog inputs with configurable ADC voltage references.  These could be used to for additional status information like temperature using an analog temperature sensor.

For example, the TMP36 chip can operate from 5V and outputs a voltage directly proportional to the temperature over the range −40°C to +125°C.  It has a 500 mV (0.5V) offset at 0°C and a 10mV per °C change (the device will read 750 mV at 25°C).  Configuring the Pi Platter ADC reference to 1.024 volts allows 10-bit ADC measurements from −40°C to +52.4°C and makes converting the ADC reading to temperature very easy.

```
	Temp in °C = ([ADC reading] - 500) / 10
```

where the ```[ADC reading]``` is the 10-bit that can be obtained from the Pi Platter using the command ```talkpp -c A1``` for ADC channel 1 or ```talkpp -c A2``` for ADC channel 2.

Information about using the ADC inputs can be found in the Pi Platter user manual.  The ```monitor_1``` may be modified to read and display the temperature from the analog input(s).

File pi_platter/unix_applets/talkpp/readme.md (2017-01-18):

## talkpp

This directory contains the code for the talkpp utilty.

talkpp is designed to run on a Raspberry Pi (or other linux computer) and allow communication with the Solar Pi Platter board either through the pseudo-tty created by the daemon ppd or the USB hardware port directly associated with the Solar Pi Platter if ppd is not running.  It provides a simple command line interface to send commands to (and get responses from) the Solar Pi Platter.  It also provides some commands to make managing time with the Solar Pi Platter's RTC easier.

It uses udev to be able to idenfity which hardware serial device belongs to the Solar Pi Platter (via the USB VID, PID and product strings).

###Building

A prebuilt binary is included here but building is very easy:

    gcc -o talkpp talkpp.c -ludev

The compiled binary may be copied to /usr/local/bin.

    sudo mv talkpp /usr/local/bin

You may have to set appropriate permissions (you will have to do this if you just copy the
prebuilt binary from git to /usr/local/bin).

    sudo chmod 775 /usr/local/bin/talkpp

libudev-dev must be installed:

    sudo apt-get update
    sudo apt-get install libudev-dev

###Usage

Type 'talkpp -u' or 'talkpp -h' for a list of command line options.

####Basic commands

ASCII command strings to be sent to the Solar Pi Platter using the '-c <string>' command.  For example to read the battery voltage:

    talkpp -c B

Or to set a servo position

    talkpp -c P1=100

talkpp will also echo the message (such as a WARN or ERR message) pending from the Solar Pi Platter when it connects.  It will also echo back any received responses for a command.

####Time management

The Solar Pi Platter RTC may be set from the Pi's clock (once it has been set) using the command.

    talkpp -s

The Pi clock may be set from the Solar Pi Platter RTC using a response in the linux 'date' command (for example when booting the Pi without any network connectivity).

    sudo date $(talkpp -t)

A human readable form of the Solar Pi Platter date can be read using the '-f' command.

    talkpp -f

An wakeup alarm time, using the linux time format ("+%m%d%H%M%Y.%S") can be set using

    talkpp -a <alarm timespec>

A wakeup time using a delta second value past the current RTC time value.

    talkpp -d <delta seconds>

Note that both methods of setting a wakeup time do not enable the wakeup alarm.  This must be done using the "C0=1" command.

    talkpp -c C0=1

Viewing the wakeup time currently set in the Solar Pi Platter in a readable form.

    talkpp -w

###Useful Shutdown Script

The following is a simple script that you can put in /usr/local/bin that will shut down the Pi and then power-down the entire system in a controlled fashion.  I name the script "powerdown".  You can cut&paste the following code into any editor and then write it out and copy it to /usr/local/bin with "sudo mv".  Be sure to set appropriate executable permissions with "sudo chmod 775 /usr/local/bin/powerdown".

    #!/bin/bash
    # powerdown script for Raspberry Pi and Solar Pi Platter
    #
    /usr/local/bin/talkpp -c O=30
    sudo shutdown now

###Questions?

Contact the author @ dan@danjuliodesigns.com

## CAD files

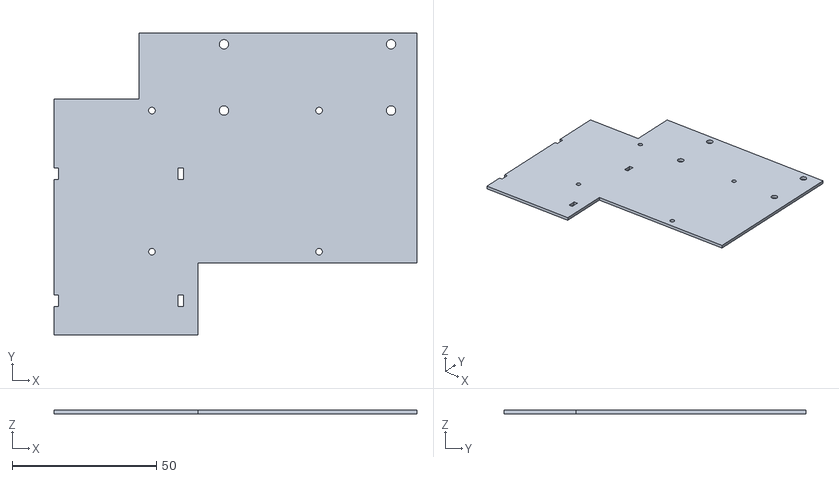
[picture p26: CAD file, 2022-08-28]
pi_platter/examples/porta_pi/baseplate/mount_plate.stl
126.0 x 105.0 x 1.50

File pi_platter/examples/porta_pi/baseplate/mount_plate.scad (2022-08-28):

//
// Simple Mounting Plate for Pi Platter and 2 cell battery on NORSMIC
// 7" touch LCD screen
//

thickness = 1.5;

//
// Plate 1 with Pi mounting holes
//
module plate1() {
    difference() {
        // Plate
        cube([91, 80, thickness]);
        
        
    }
}

//
// Complete assembly
//
difference() {
    // Base Plate
    cube([126, 105, thickness]);
    
    
    // LCD Mounting holes (mount plate to LCD standoffs)
    translate([34, 29, -0.5]) {
        cylinder(h=thickness+1, r=1.15, $fn=120);
    }
    translate([92, 29, -0.5]) {
        cylinder(h=thickness+1, r=1.15, $fn=120);
    }
    translate([34, 78, -0.5]) {
        cylinder(h=thickness+1, r=1.15, $fn=120);
    }
    translate([92, 78, -0.5]) {
        cylinder(h=thickness+1, r=1.15, $fn=120);
    }
    
    // Pi Platter Mounting holes
    translate([59, 78, -0.5]) {
        cylinder(h=thickness+1, r=1.625, $fn=120);
    }
    translate([117, 78, -0.5]) {
        cylinder(h=thickness+1, r=1.625, $fn=120);
    }
    translate([59, 101, -0.5]) {
        cylinder(h=thickness+1, r=1.625, $fn=120);
    }
    translate([117, 101, -0.5]) {
        cylinder(h=thickness+1, r=1.625, $fn=120);
    }
    
    // Battery zip-tie cut-outs
    translate([-0.5, 10, -0.5]) {
        cube([2, 4, thickness+1]);
    }
    translate([-0.5, 54, -0.5]) {
        cube([2, 4, thickness+1]);
    }
    translate([43, 10, -0.5]) {
        cube([2, 4, thickness+1]);
    }
    translate([43, 54, -0.5]) {
        cube([2, 4, thickness+1]);
    }
    
    // Remove unnecessary material
    translate([50, -0.5, -0.5]) {
        cube([91.5, 25.5, thickness+1]);
    }
    translate([-0.5, 82, -0.5]) {
        cube([30, 25.5, thickness+1]);
    }
}

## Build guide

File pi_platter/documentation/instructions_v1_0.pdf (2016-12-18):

### Solar Pi Platter Operating Instructions for Firmware 1.0, Board Rev 03 Ver 12/17/2016

Assembly Notes
1. Attach the plastic stand-offs to the Raspberry Pi Zero board and tighten before installing on the Pi Platter. This is because of the fit on the Pi against the HDMI and Power USB connectors and proximity to other Pi Zero components. It’s easier to tighten the stand-off on the bottom of the board while holding the stand-off on the top of the board motionless.
2. Attach the battery first then any other power source.

Hardware Notes
The Pi Platter is designed for applications where the Pi will be powered down a significant amount of time while the battery is recharged. It can operate in a continuously powered situation for low load systems as described below. In this case the Pi would probably be required to do some active power management of USB peripherals. In general, it is assumed that the Pi uses the ability to power on and off the USB connectors as a way to save power.

Charging sources include low impedance USB power supplies connected to the Micro-B USB connector CON2 or high impedance supplies like a solar panel. The Pi Platter is designed for 6V panels (which typically have a maximum open circuit voltage of 7V) connected to the 5.5x2.1mm jack, CON1. Six- or 9-W panels are a good match (6-watt for areas with a lot of sunlight). The absolute maximum input voltage is 20V, however the charger will only operate with input voltages in the range of 3.5 - 7.0V.

Additional functionality is available with the USB power supply. The Pi Platter uses that source to directly power the system and charge the battery (current limits may apply based on the maximum current output of the USB power supply) automatically switching to powering the system from the battery when USB power is removed.

A single-cell, 3.7V, Li-Ion battery must be connected to either CON3 with a JST connector (compatible with batteries from both Sparkfun and Adafruit) or directly wired to CON4. The Pi Platter is designed for Li-Ion batteries with capacities between about 1000 mAh to 5000 mAh. Sparkfun claims that their batteries using the JST connector shouldn’t have a load current in excess of 1A so CON4 should be used for systems that will have a higher load current as described below. CON4 also provides a connection for an external 103AT-4 thermistor that can be attached to the battery to limit battery charging in extreme temperature situations. Remove J2 to use an external thermistor.

All power inputs (charger and battery) are reverse polarity protected. The Pi Platter also protects the battery against any internal shorts or massive over current conditions.

Maximum current output is designed to be 2A at 5V. The boost converter that converts the battery voltage to 5V should run with an efficiency of 92-95% for output currents of a 1A or less. Its efficiency falls off as the battery voltage falls and as current rises above 1A. The following calculations assume 85% efficiency for an output current of 2A with a battery voltage of 3.1V and 93% efficiency for an output current of 2A with a battery voltage of 4.2V. Current consumption from the battery goes up as the battery voltage goes down.

- Maximum high-battery current draw (2A 5V load): 5V/4.2V/0.93 * 2 = 2.6A
- Maximum low-battery current draw (2A 5V load): 5V/3.1V/0.85 * 2 = 3.8A

The maximum battery charge current is 750 mA. This was chosen to support a variety of battery capacities and input power sources that match the intended functionality of this product. This charge current will be available from a low impedance source such as a 5V 1- or 2A USB charger when the current required by the rest of the system can also be supplied by the low impedance source. Charge current will be reduced if the low impedance voltage levels droop due to excessive current draw. It may not always be available from a solar panel depending on the amount of light and the maximum power output of the panel. The Pi Platter will try to optimize the power it can get out of the solar panel by backing down on the charge current to keep the charge voltage above the battery voltage. Any load being taken by the system will count against the charge current going into the battery.

The maximum continuous recharge time when charging from a high-impedance power source such as a solar panel is 10 hours. The charger enforces these timeouts (10 hours with a high-impedance source and 20 hours with a low-impedance source) to protect the battery. The charger can start another charge sequence if the battery voltage drops approximately 100 mV or if the charge supply stops (e.g. the solar panel sees dark). This should present no problems where the panel is sized correctly and there is sufficient sun to fully charge the battery in less than 10 hours. It may be necessary to limit the time the Pi is powered up to ensure these conditions.

Base current should be assumed to be about 320 mA at 5V (400 - 560 mA battery draw). This includes the Pi Zero board and the initialized USB Subsystem on the Pi Platter, but no USB peripherals. Ethernet adds about 75-80 mA from the 5V supply.

USB Connector CON 5 is identified as USB devices 2 and 3. Power to these two USB devices may be switched on and off (on by default). USB Connector CON7 is identified as USB device 1. There is a 1A current limit imposed by the USB power switch for CON5. CON6 has no current limiting. Over-current may cause the boost converter to shut down when running on batteries or the USB power source to current limit.

PWM1 and PWM2 expansion ports are identified as PWM devices 1 and 2 respectively.

Analog inputs A1 and A2 are identified as Analog devices 1 and 2 respectively. The Analog inputs are converted to a value with a configurable voltage reference. The voltage reference may be set to one of three fixed, precision, values (1.024, 2.048, 4.096 volts) for making absolute measurements or it may be set to the PMIC/RTC power supply rail (VD) for making relative measurements. Input voltages on A1 and A2 should never exceed VD or damage to the PMIC/RTC may occur.

The PC (“Power Control”) expansion in port is connected in parallel to the power button. External circuitry (e.g. a relay or N-Channel MOSFET) can pull this signal low to simulate a button press. Assert the signal low for more than 2 seconds to power on the board. Assert the signal low for more than 6 seconds to power off the board.

The VD, VB, 5 and 3.3 expansion connections provide access to the various power rails in the system. VD is the PMIC/RTC VCC signal and might be useful as the reference voltage for devices using the Analog inputs and setting Vref to VCC. VB is the battery voltage. Current should be limited to 500 mA. 5 is the 5V output. 3.3 is a 3.3V output (that is shared with the USB and Ethernet subsystem). Output current on the 5V line is limited to a system total of 2A. Output current on the 3.3V line is limited to 100 mA.

G expansion connections are connected to ground. There are several to simplify connecting to various external devices.

The ethernet expansion port is designed for use with the Sparkfun BOB-13021 RJ45 MagJack breakout board (Adafruit has no similar product).

Default Configuration
- Low Battery Threshold (configurable): 3.6V
- Critical Battery Threshold (configurable): 3.1V
- Battery Start Under-voltage threshold: 3.2V
- Battery Restart voltage threshold: 3.8V
- Battery Critical detection to turn-off: 30 seconds
- Low Battery Warning Enabled
- Critical Battery Warning Enabled
- Battery Restart Disabled
- USB Fault Warning Enabled
- Power on USB Port 2: Enabled
- Power on USB Port 3: Enabled
- Analog 1 Reference: PMIC/RTC VCC (VD)
- Analog 2 Reference: PMIC/RTC VCC (VD)
- PWM Mode: Normal PWM - Slow

Operational Notes
The Pi Platter starts up in sleep mode when power is first applied and the real-time clock initialized to 0 seconds. Press the button for 2 seconds to turn power on. Press the button for 6 seconds to turn power off.

The Pi Platter will not turn power on while the battery voltage is less than the Battery Start Under-voltage Threshold.

Power can be turned on when the board is sleeping by the RTC. The RTC is simply a 32-bit second counter and can be associated with any time keeping scenario the user wants. It supports a single 32-bit Wakeup Time that can be enabled and is triggered when the RTC matches the Wakeup Time and the board is sleeping. There is also a 32-bit Wakeup Repeat time that is added to Wakeup Time every time an Wakeup condition is detected (Wakeup Time matches RTC and is enabled). This makes it possible to create a simple system that turns on the Pi periodically with software on the Pi turning the system off after it has completed its functions. The RTC runs as long the battery is connected.

Power can also be turned on when the battery voltage is charged above the Battery Restart Threshold. This value is stored in EEPROM (default 3.8 volts) and can be automatically enabled every time the Pi is powered by the EEPROM Battery Restart Enable or selectively for the next charge cycle by the Restart Enable Control register. This functionality is disabled by default.

By default all three USB connectors are enabled when the board is turned on. This is to allow the user to connect a keyboard/ mouse in order to do initial configuration of their system. They can reconfigure the Pi Platter so that either of the USB ports on CON5 are disabled when the board turns on for power savings.

The PWM outputs are set to 0 (or Servo midpoint if PWM Mode is set to Servo) when the board is first turned on.

The Pi Platter shows up as an ACM serial port to the Raspberry Pi. Depending if any other ACM serial devices are connected to one of the USB ports, it will show up as /dev/ttyACM0 (or /dev/ttyACM1 if there is a USB ACM device, etc). The PMIC/RTC micro-controller is connected to USB port 4 on the board’s hub so will enumerate after other USB ACM devices. The baud rate does not matter since it is a USB ACM device.

Warnings are enabled by default. They are simple text strings with the form “WARN <N><CR><LF>” where <N> is a number identifying the warning type, <CR> is the carriage return character, and <LF> is the linefeed character. A serial connection must be open in order to receive any warning messages. Individual warning messages may be disabled.

- “WARN 0”: Low Battery Warning Message
- “WARN 1”: Critical Battery Warning Message
- “WARN 2”: USB Fault Detected Message

Voltage levels must persist at Low or Critical levels for at least 5 seconds before a warning is issued. This prevents momentary voltage drops (from a servo, for example) from prematurely triggering a warning message (or power down).

Power will turned-off a programmable time after the critical battery voltage level is detected. Power cannot be switched back on, either by the power button or a RTC Wakeup if the battery voltage is less than or equal to the Start-up under-voltage. The Wakeup Repeat interval is added to the Wakeup Time so that the board has a chance to power up at the next Wakeup Time if the battery has been sufficiently charged before then.

A watchdog function can be enabled by writing a watchdog timeout period (in seconds 1-65535) to a control register. Software running on the Pi must write a new watchdog timeout to this register (or the value 0 to disable the watchdog timeout function) before the specified number of seconds passes or the Pi Platter will turn the 5V power off (Pi and USB) for 5 seconds. Reading the register indicates how many seconds remain before the watchdog reset.

Command Interface
Commands are simple ASCII sequences with two forms terminated by a Carriage Return character (<CR>), shown below, sent to or received from the Pi Platter’s ACM Serial interface (using the “screen” utility, for example). The first form is used to set a value. The second form is used to query a value. Each command is a single upper-case ASCII character, <CMD>, that is selected to mnemonically represent its function. A command may be followed by a optional numeric index, <INDEX>, required when it applies to more than one item (for example, USB port, PWM channel or Analog input). Values, <VALUE>, to be set are numeric values.
1. Form 1 (Set): <CMD>[<INDEX>]=<VALUE><CR>
2. Form 2 (Query): <CMD>[<INDEX>]<CR>

All parameters, <INDEX> or <VALUE>, are base-10 numeric values. All other characters besides the <CMD> character, numbers “0”-“9”, the “=“ character and the Carriage Return character are ignored. Illegal or malformed commands cause the Pi Platter to respond with an error message with the form “ERR <N><CR><LF>” where <N> is a number identifying the type of error.

- “ERR 0”: Unknown Command (The command character, <CMD>, did not match any of the supported commands).
- “ERR 1”: Illegal Index value (The index value, <INDEX>, did not apply or was out of range)
- “ERR 2”: Command does not support Form 1 (Set). It is a Query-only item.

The Pi Platter does not echo back commands. It only generates responses to Queries, warning messages or command error messages. You can enable local echo if you are using a terminal emulator program. The Pi Platter command processor looks at the last characters before a <CR> entered to process commands. This means you can correct commands by just typing what you really meant before hitting <CR>. The Pi Platter also appends a Line Feed, <LF>, character to messages it sends to make them easier to see in a terminal emulator. It ignores <LF> characters sent to it.

Commands are grouped into several categories.

1. Power Management - Monitor battery voltage, Set/Query the USB Port power, initiate a power-down timeout.
2. Real Time Clock - Set/Query the RTC, Wakeup Time and Wakeup Repeat Time.
3. User Peripherals - Query Analog Voltage readings, set PWM output values.
4. Control and Status - Set/Query operational control registers, Query the system Status.
5. System Configuration - Set/Query configuration values that are stored in EEPROM and are used to configure operation each time the board is powered up.

Power Management

Battery Voltage - “B” - Supports the Query form only. Returns the current battery voltage in volts with 10 mV resolution.

B<CR> - Returns the battery voltage (B=<VOLTS><CR><LF> - for example “B=4.05”)

Power Off - “O” - Supports both forms. Set initiates a power-down in the specified number of seconds. Query returns the number of seconds until power is turned off. A value of 0 means the power down timer is not operating. The time value may range from 1-255 seconds.

O=30<CR> - Sets a 30 second timeout until power down
O<CR> - Returns the number of seconds until power down (O=<NUM><CR><LF>)

USB Port Power Enable - “U” - Supports both forms. Set allows turning on or off an individual, indexed, USB port. Query returns the current power status of the indexed USB port. The index value may range from 1 - 2 for USB Ports 2 and 3. The power control value is 0 to turn a port off and 1 to turn a port on.

U1=1<CR> - Turns USB Port 2 on
U2=0<CR> - Turns USB Port 3 off
U1<CR> - Returns the power control state for USB Port 2 (U1=<N><CR><LF> where <N> is 1 or 2)

Real Time Clock

Current Time - “T” - Supports both forms. Set allows setting the current RTC second count (32-bit unsigned number). Query returns the current RTC second count.

T=1000<CR> | - Sets the RTC to 1000 seconds
T<CR> | - Returns the current RTC value (T=<SECONDS><CR><LF>)

Wakeup Time - “W” - Supports both forms. Set allows setting the Wakeup Time (32-bit unsigned number). Query returns the current Wakeup Time. Note that Control Register Wakeup Enable (C0) must be set to 1 to enable wakeup to occur when the current time matches the wakeup time and the device is powered down.

W=1100<CR> | - Sets the Wakeup Time to 1100 seconds
W<CR> | - Returns the current Wakeup Time (W=<SECONDS><CR><LF>)

Wakeup Repeat Time - “R” - Supports both forms. Set allows setting the Repeat Time (32-bit unsigned number). This is the value added to the Wakeup Time when the RTC second count equals the Wakeup Time and Wakeup Enable is set to 1 (it is added when the board is both sleeping and when it is powered up). Query returns the current Repeat Time. A value of 0 means do not modify the Wakeup Time. Control Register Wakeup Enable (C0) is not cleared if the Wakeup Repeat Time is non-zero and the Wakeup Time is updated whenever Current Time matches it.

R=86400<CR> | - Sets the Wakeup Repeat Time to 86400 seconds (1 day)
R<CR> | - Returns the current Wakeup Repeat Time (R=<SECONDS><CR><LF>)

User Peripherals

Analog Input - “A” - Supports the Query form only. Returns a 10-bit unsigned value from the indexed Analog Input. The number is referenced to the current Analog Channel reference setting. For example, if the Analog Channel reference is set to 1.024 volts then a 1.0 volt signal would return (1.0/1.024) * 1023 = 999. The index, <INDEX>, may have the value 1 or 2.

A1<CR> | - Returns the 10-bit unsigned value from Channel 1 (A1=<VALUE><CR><LF> where <VALUE> = 0 - 1023)
A2<CR> | - Returns the 10-bit unsigned value from Channel 2

PWM Output - “P” - Supports both forms. Set allows setting a PWM value (8-bit unsigned value, 0-255) to the indexed PWM Output. Query returns the current value for the indexed PWM Output. The index, <INDEX>, may have the value 1 or 2.

P1=40<CR> - Sets PWM 1 to 40
| P2<CR> | - Returns the 8-bit value from PWM 2

Note that the PWM subsystem has two different modes of operation. Normal PWM Mode is a traditional PWM function where the time the PWM output is set to 1 is directly proportional to the value set for that channel. This is the type of PWM operation that an Arduino provides with the “analogWrite” function on a PWM pin. The Pi Platter supports three different periods for Normal PWM Mode in order to support different uses of a PWM output. Fast mode is useful for generating a voltage level (simple DAC) using a RC network. Slow mode is useful for dimming a LED.

1. | Fast | - 21.33 uSec/period (46875 Hz)
2. | Medium | - 341.33 uSec/period (2930 Hz)
3. | Slow | - 1.364 mSec/period (732 Hz)

Servo PWM Mode is a special mode designed to support hobby Servo motor devices where the period is 20 mSec but the signal on time varies around a nominal servo mid-point on-setting of 1.5 mSec. Although individual servo devices vary wildly, the common understanding is that the servo is controlled over its entire mechanical range with settings ranging from 1 mSec (fully rotated to one side) to 2 mSec (fully rotated to the other side). The Pi Platter maps its 8-bit servo values to servo on settings from 0.8173 mSec to 2.1827 mSec with the mid-point on-setting of 1.5 mSec being a value of 128. The additional range supports the variation in individual servo mechanisms. A value of 0 sets a servo-on setting of 0.8173 mSec and a value of 255 sets a servo on-setting of 2.1827 mSec. The Pi Platter sets a value of 128 (mid-point) when PWM Mode is selected. Since each servo motor may vary, the user must determine their own limits. Exceeding a limit may damage the servo and will consume large amounts of current possibly causing the boost converter to shut down.

Control and Status

Control Register - “C” - Supports both forms. Set allows setting an indexed control register to a value. Query returns the current value of an indexed control register. The index value selects a control register. The legal control register index values are shown below along with the legal values for each control register.

C0=1<CR> - Sets Control Register 0 to 1
C1<CR> - Returns the value of Control Register 1

The Pi Platter has the following control register index values. Default values may be set from EEPROM.

0 - Wakeup Enable: 1 = Wakeup Enable, 0 = Wakeup Disable. Cleared automatically when a wakeup occurs unless the Repeat Time is non-zero.
1 | - Low Battery Warning Enable: 1 = Enable Message, 0 = Disable message
2 | - Critical Battery Warning Enable: 1 = Enable Message, 0 = Disable message
3 | - USB Fault Warning Enable: 1 = Enable Message, 0 = Disable message
4 | - Analog 1 Reference: (see below for Analog reference values)
5 | - Analog 2 Reference: (see below for Analog reference values)
6 | - PWM Mode: (see below for PWM Modes. Note the PWM Mode applies to both PWM channels)
7 | - Restart Enable: 1 = Enable restart when battery voltage exceeds Battery Restart Threshold, 0 = Disable restart
8 | - Watchdog Control: Set to a non-zero 16-bit second count (1-65535) to enable watchdog reset, 0 to disable

Analog Reference Values

0 | - Analog Channel Vref = PMIC/RTC VCC (PMIC/RTC power input - voltage on expansion port VD connection)
1 | - Analog Channel Vref = 1.024 Volts
2 | - Analog Channel Vref = 2.048 Volts
3 | - Analog Channel Vref = 4.096 Volts

PWM Modes

0 | - Normal PWM - Fast Period
1 | - Normal PWM - Medium Period
2 | - Normal PWM - Slow Period
3 | - Servo PWM (Initial servo value set to mid-point: 128)

Status - “S” - Supports the Query form only. Returns an 8-bit mask containing various status information.

S<CR> - Returns the 8-bit status value.

The return value is a number 0 - 255 but can be broken down by converting to a hex value and looking at the following bit positions.

bit 7: USB Fault Detected: set when the USB Power Switch is indicating a USB Fault (over-current or short).
bit 6: Reserved, will return 0.
bit 5:4 Power Up Reason: (see below).
bit 3: Battery Charging: set if the Charger subsystem is supplying current to charge the battery and/or operate the system bit 2: USB Supplying Power: set when power is being supplied by an external USB power supply, clear when it is being supplied by the battery.
bit 1: Battery Critical: set when the battery voltage is below the Battery Critical threshold, clear when the battery voltage is above the Battery Critical threshold.
bit 0: Battery Low: set when the battery voltage is below the Battery Low threshold, clear when the battery voltage is above the Battery Low threshold.

Power Up Reason (2-bits)
00: Alarm
01: Button
10: Battery Restart (battery charge exceeded Battery Restart Threshold to power-up the board) 11: Watchdog Restart (Power was cycled for 5 seconds because of a watchdog timeout)

Version - “V” - Supports the Query form only. Returns the current board type and firmware revision as a 24-bit unsigned value (3 bytes). The lower byte (bits 7:0) contains the firmware minor number. The middle byte (bits 15:8) contains the firmware major number. The minor number is incremented for bug fixes and minor modifications to existing functionality. The major number is incremented for new functionality or user-visible modification of existing functionality. The minor number is the fractional value reported by the PMIC/RTC USB Version field. The major number is the integer value reported by the PMIC/RTC USB Version field.

The upper byte (bits 24:16) contain the board ID (which is 0x01 for the Pi Platter).

V<CR> - Returns the version (V=<VERSION><CR><LF>, Version 1.0 returns “V=65792”)

System Configuration

EEPROM - “E” - Supports both forms. Set allows setting an indexed Configuration Value that is stored in the PMIC/RTC’s EEPROM memory that persists across power-cycles (including battery removal). Query returns the value of an indexed Configuration Value. Configuration Values are read each time the board is powered-up and are used to set the default operating conditions. Setting a Configuration Value does not take effect until the Pi Platter has powered down and then powered up the Pi Zero.

E9=0<CR> - Sets Configuration Index 9 (USB 1 Default Enable) to 0 (off).
E14<CR> - Returns the value of Index 14 (PWM Mode)

The Configuration Value indexes are shown below along with their legal values.

0: | Battery Low Warn Threshold. A 16-bit unsigned integer (0-1023) that sets the Low Battery Threshold (see below).
1: | Battery Critical Threshold. A 16-bit unsigned integer (0-1023) that sets the Critical Battery Threshold (see below).
2: | Battery Start Under-voltage Threshold. A 16-bit unsigned integer (0-1023) that sets the under voltage Threshold.
3: | Battery Restart Threshold. A 16-bit unsigned integer (0-1023) that sets the restart voltage Threshold.
4: | Battery Critical to Turn-off Timeout. An 8-bit unsigned integer that sets the number of seconds (0-255).
5: | Battery Warn Message Enable. Set to 0 to disable Low Battery Warning Messages, 1 to enable.
6: | Battery Critical Message Enable. Set to 0 to disable Low Battery Warning Messages, 1 to enable.
7: | Battery Restart Enable. Set to 0 to disable setting the Battery Restart Enable when powering up, 1 to enable.
8: | USB Fault Message Enable. Set to 0 to disable Low Battery Warning Messages, 1 to enable.
9: | USB Port 2 Default Power Enable. Set to 0 to disable power to USB Port 2 on power-up, 1 to enable.
10: | USB Port 3 Default Power Enable. Set to 0 to disable power to USB Port 3 on power-up, 1 to enable.
11: | Analog 1 Default Reference. One of the 4 Analog Reference Values for Analog 1 (0 - 3).
12: | Analog 2 Default Reference. One of the 4 Analog Reference Values for Analog 2 (0 - 3).
13: | PWM Mode. One of the 4 PWM Modes (0 - 3).

Low and Critical Battery Threshold Calculations
The Low and Critical battery threshold configuration values may be calculated as follows. They are the ADC count threshold based on the Pi Platter battery sense circuitry and a Vref of 1.024 volts. Vthresh is the voltage level expressed in volts (e.g. 3.6).

Threshold (0-1023) = ((Vthresh * 0.2362)/1.024) * 1023

Note that the Pi Platter has been preset with reasonable values for Li-Ion batteries. These values should only be changed for specific reasons.

Start Under-voltage and Restart Threshold Calculations
The Start Under-voltage and Restart threshold configuration values may be calculated as follows. They are the ADC count threshold based on measuring a 1.024 volt reference against the PIC VDD power (through a diode with an estimated 0.15 volt Vf drop) when powered by the battery. Vthresh is the voltage level expressed in volts (e.g. 3.2).

Threshold (0-1023) = (1.024 / (Vthresh - 0.15)) * 1023

Special Note for EEPROM access
The PMIC/RTC EEPROM has a limited number of write cycles. Depending on the type of Configuration Value Index being written, the memory will only support a few tens-of-thousands of updates. While this should be sufficient for the purpose it was intended (making a custom system configuration) software should not make changes to the System Configuration unless absolutely necessary (do not treat EEPROM like a RAM variable).

Battery Restart Operation
The Battery Restart mechanism allows the board to automatically power-on the Pi when the battery is charged to a configurable voltage (Battery Restart Threshold). This functionality is disabled by default and may be enabled in one of two ways. The Battery Restart Enable EEPROM configuration entry can set the enable every time the Pi is powered. This may be useful in an application that should run whenever there is sufficient power in the battery and software running on the Pi does not have to do anything (other than execute an orderly shutdown if required to prevent SD card corruption).

If the Battery Restart Enable configuration entry is clear then system software running on the Pi can set the Restart Enable Control register to 1 to enable a restart on the next power down only. In this case the Restart Enable will be disabled on the next power up and the Pi must, again, enable it for the power cycle. This allows the Pi set setup a special condition if necessary.

The Battery Restart mechanism is only applied when power is shut down. It is checked once per second when the RTC is updated while the board is sleeping.

Watchdog Operation
A watchdog function may be enabled that requires software on the Pi to write a control register within a specified period. Failure to write the control register causes the +5V power to be cycled to the Pi and IO subsystem for 5 seconds.

By default the watchdog function is disabled. Writing a non-zero value to the Watchdog Control control register starts a watchdog timeout. The current watchdog timeout value can be obtained by reading the register. Software on the Pi must either periodically reset the watchdog timer by rewriting the watchdog value or disable it by writing the value 0 to the control register.

For example

C8=60<CR>

sets a 60 second watchdog timeout. Software must write C8=60<CR> again within 60 seconds or write C8=0<CR> to disable the timer.

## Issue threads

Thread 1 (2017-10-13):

solar pi platter does not boot any more

hplus28, 2017-10-13:
Hi,
Mi pi platter board stopped working suddenly. i can't manage to turn it on anymore by pressing the button for over 2 seconds. I have to plug unplug the usb power several times and occasionally it happens to boot. But even then, the board led stays on for a few seconds, the raspi led turn on then off and the pi-platter board  slowly fades-out. I've tested the raspi board alone, it works like a a charm.
The board was working ok, and i only unplugged the battery (board was off) before the problem began. Have i broken the board?
I just noticed that from the begining the board was always getting really hot when operating. (charging over usb or using the battery) I was wondering  how come this board intended to be power efficent could heat  that much.....

Thanks
Hplus

danjulio, 2017-10-13:
Sorry you're having troubles.  I suspect that the on-board PIC lost its programming.  There have been a couple of other cases of this happening.  I am investigating but it may be that I set the brown-out voltage fuses incorrectly and it tries to execute code as the power fails causing corruption.

Contact me via my email listed on github and we can figure out the best way to get you up and running again.

The board does get warm during charging.  This is normal operation of the linear charge regulator.  It also gets warm during operation from the USB Hub.  The board is designed to draw heat out of the chips onto the copper on the bottom of the PCB.

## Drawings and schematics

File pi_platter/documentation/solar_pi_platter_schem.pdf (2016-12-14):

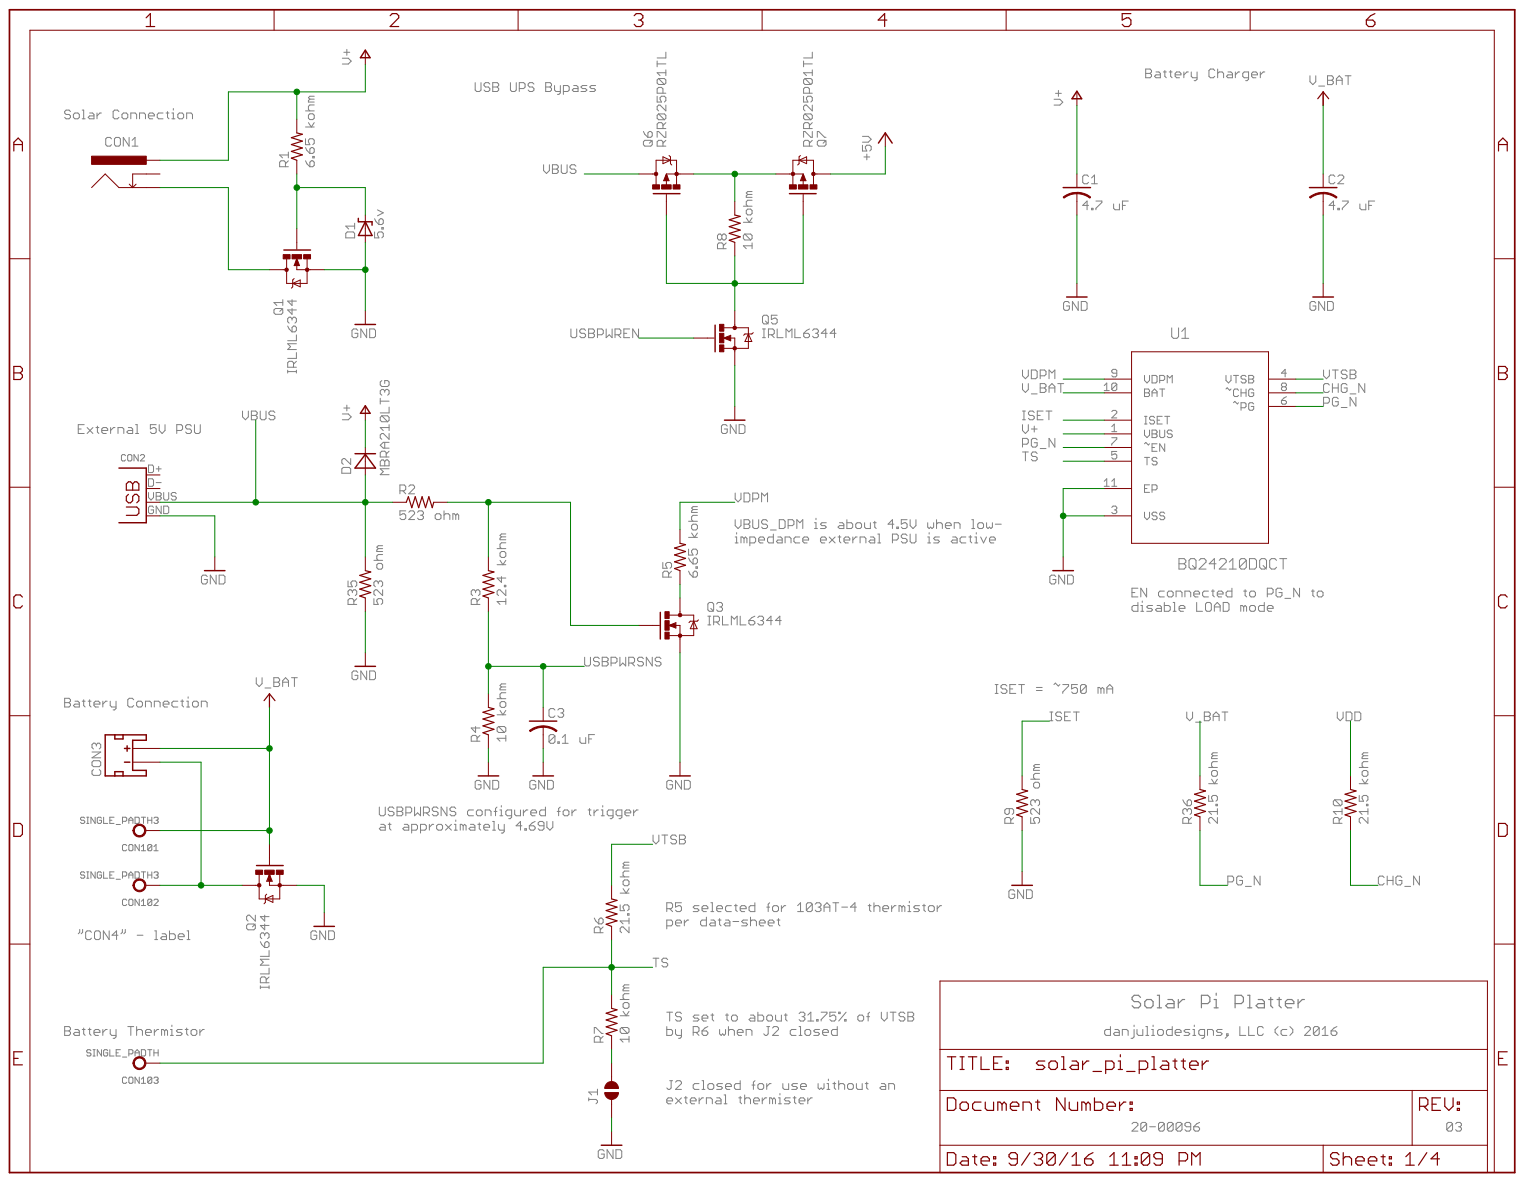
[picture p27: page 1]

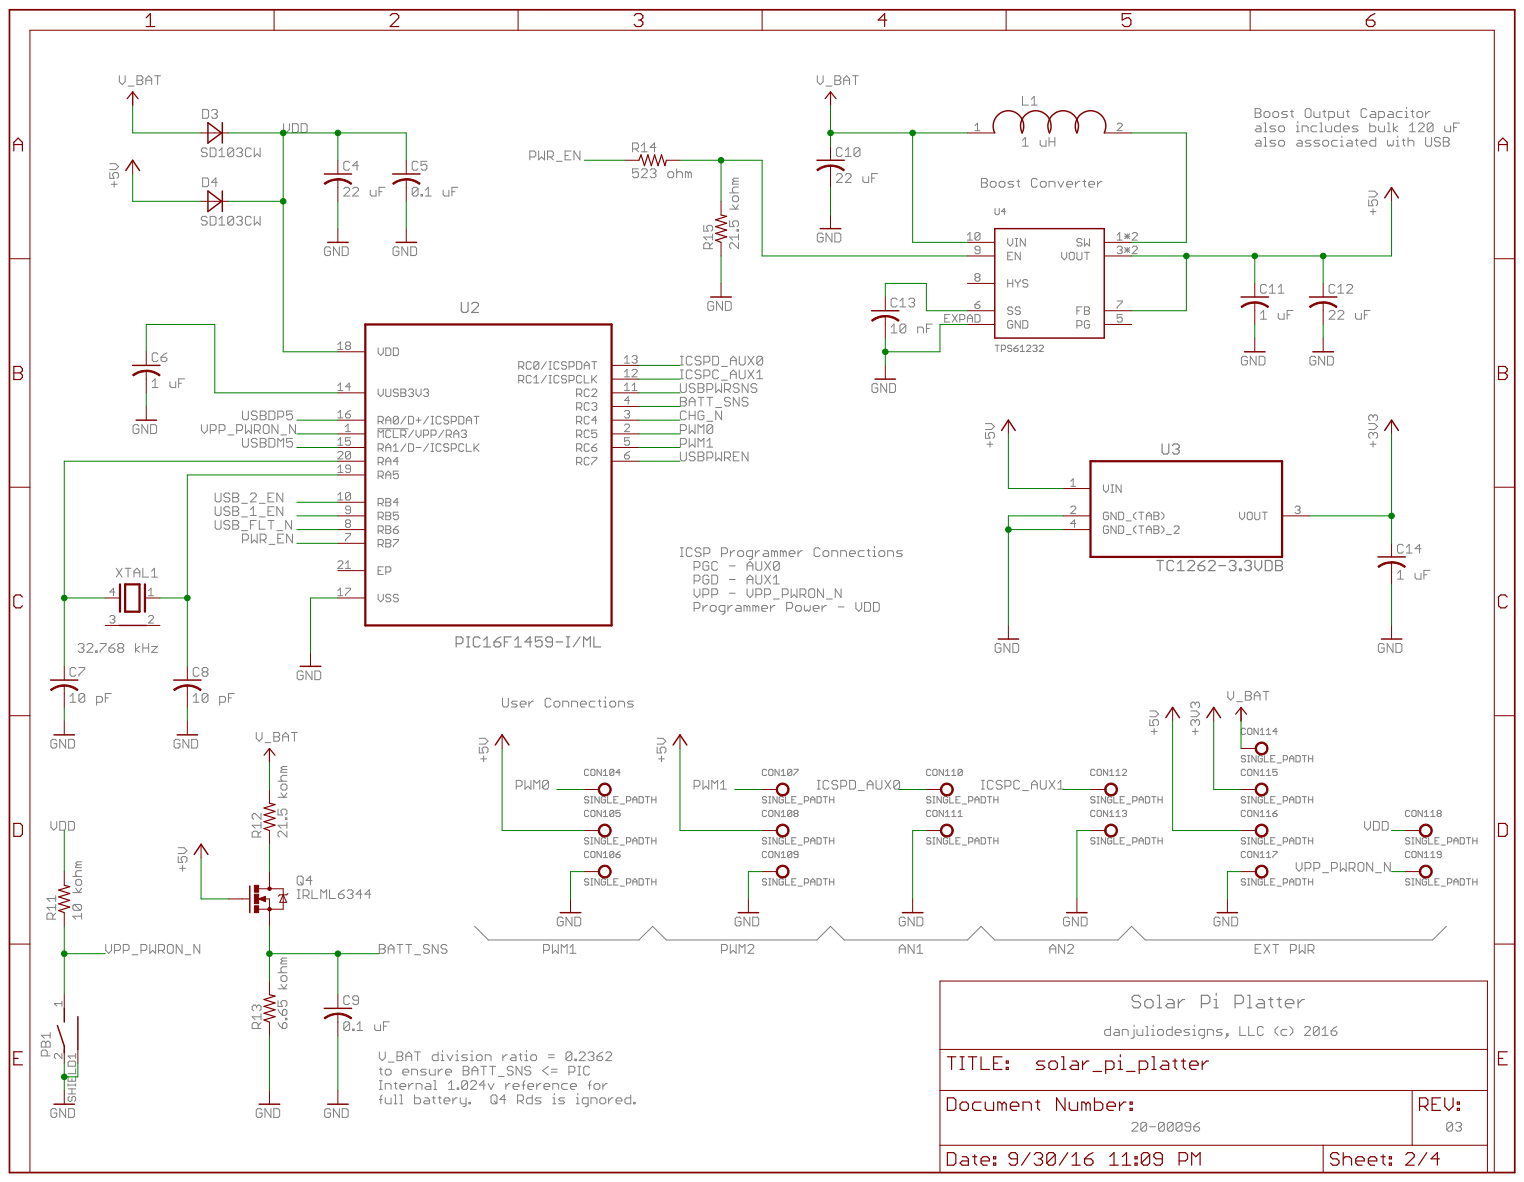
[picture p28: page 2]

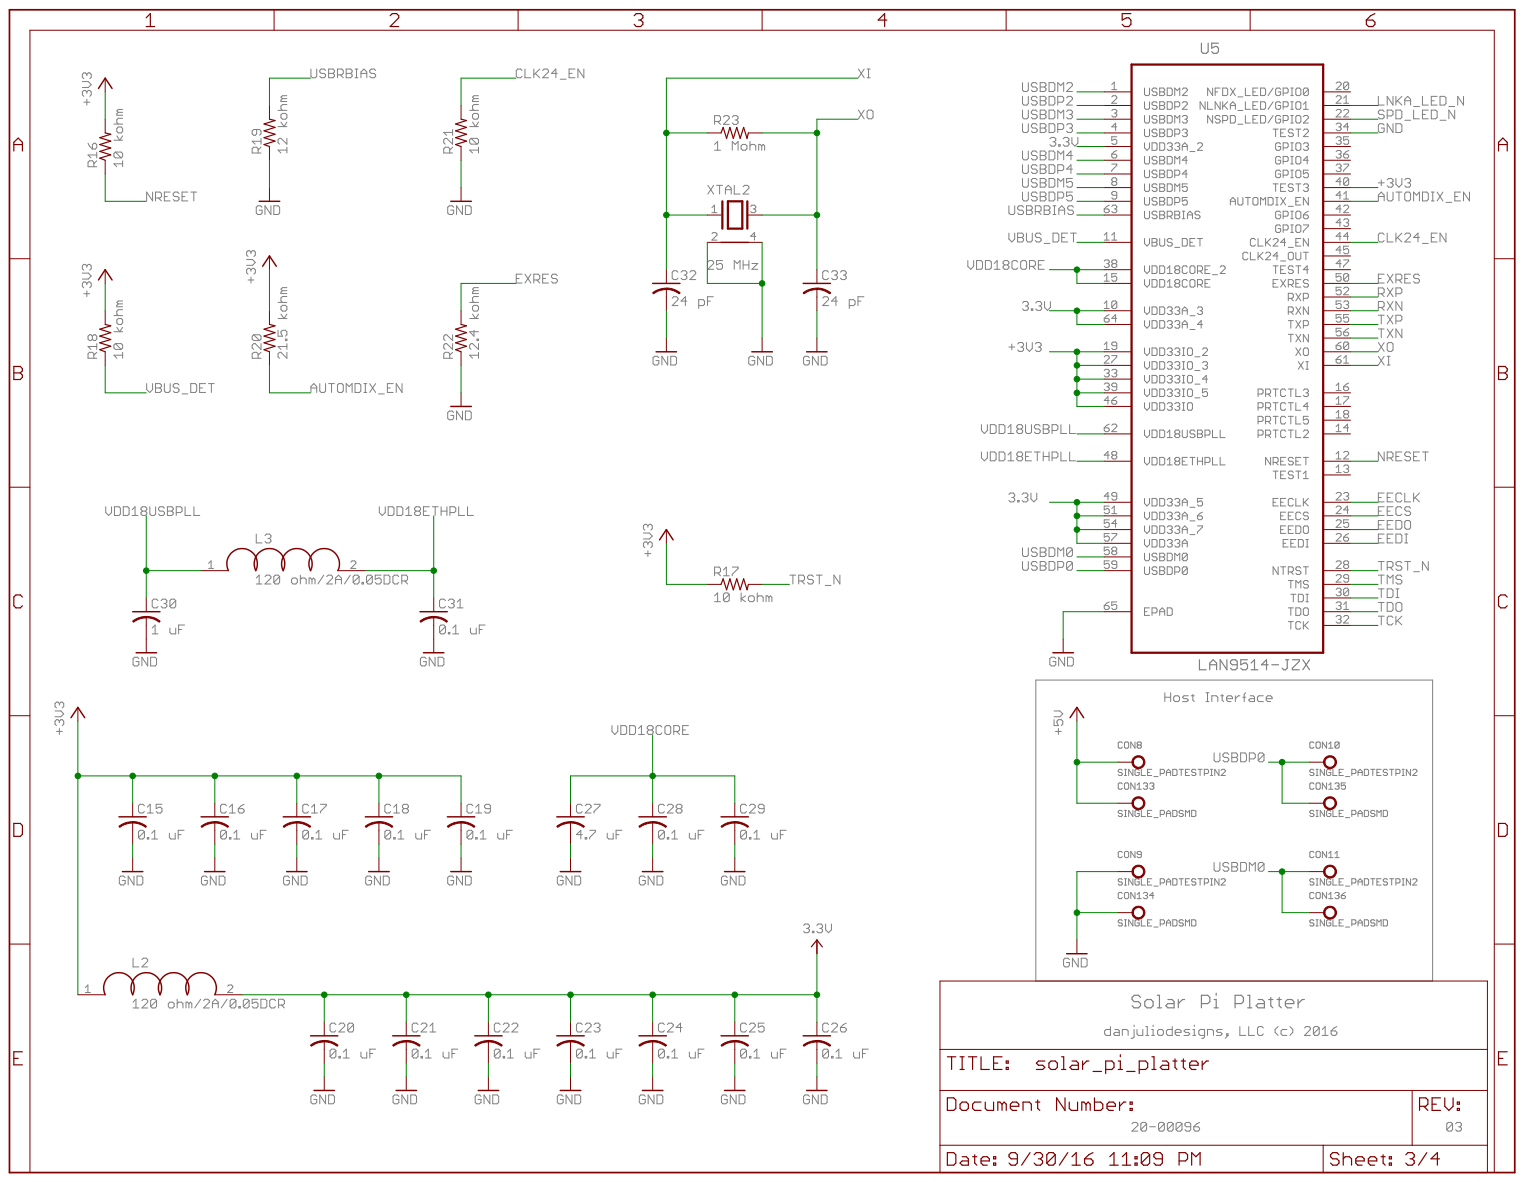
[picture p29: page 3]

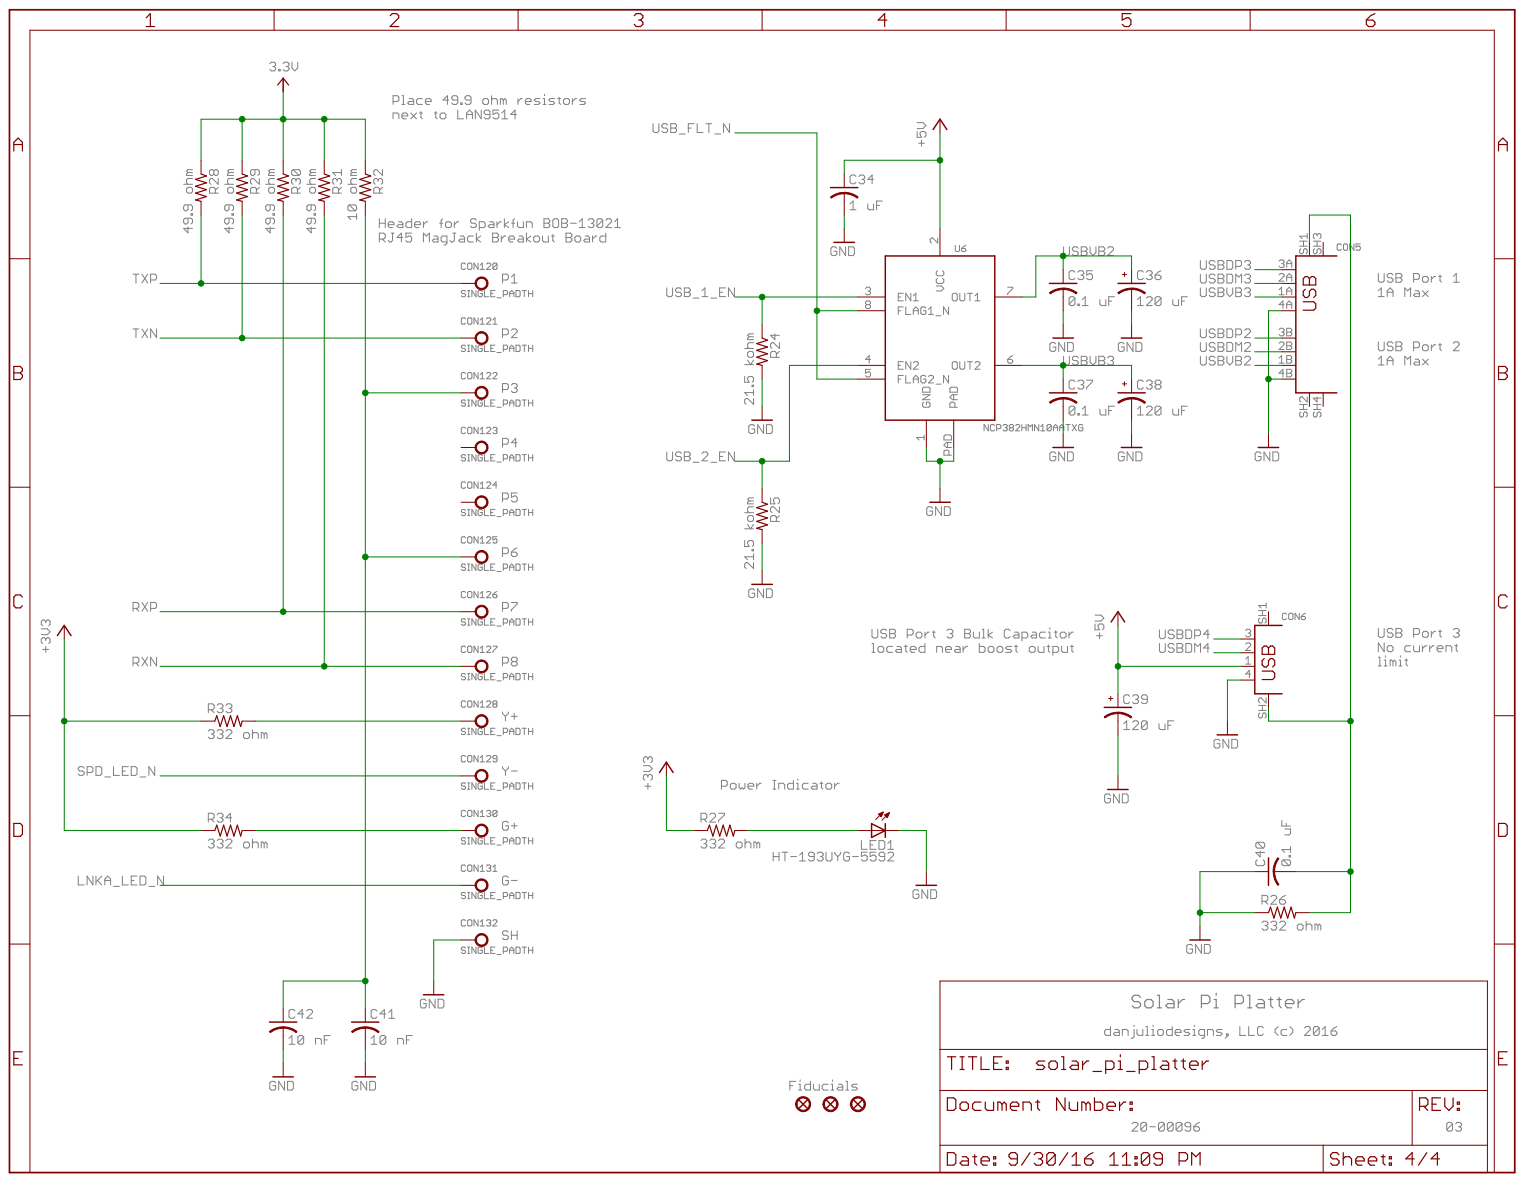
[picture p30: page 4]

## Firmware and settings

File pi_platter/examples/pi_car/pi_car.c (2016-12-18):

// Program to control the pi_car
//
//   pi_car [-p <serial device>]
//
// by default the program attempts to open /dev/ttyACM0
//
//   -p <serial device> : Specify the serial port to use (e.g. /dev/ACM1)
//
// Build: gcc -o pi_car pi_car.c -lwiringPi
//
#include <arpa/inet.h>
#include <ctype.h>
#include <fcntl.h>
#include <sys/ioctl.h>
#include <sys/types.h> 
#include <sys/socket.h>
#include <netinet/in.h>
#include <errno.h>
#include <stdio.h>
#include <stdlib.h>
#include <string.h>
#include <termios.h>
#include <time.h>
#include <unistd.h>
#include <wiringPi.h>

#define MAX_SER_NAME_CHARS  64
#define MAX_CMD_CHARS       128
#define MAX_RSP_CHARS       64

// MAX_WAIT_TIME is uSec to wait for a response after sending a command
// (seems to need to be pretty high a pi)
#define MAX_WAIT_TIME       500000

#define TCP_PORT 8082


// Command word masks
// 32-bit command value
//   bit 24: request sensor (A1)
//   bit 23: shutdown
//   bit 22: request light enable (U1)
//   bit 21: request sensor (A2)
//   bit 20: request status (S)
//   bit 19: request battery voltage (B)
//   bit 18: light enable
//   bit 17: dir2
//   bit 16: dir1
//   bit 15:8: pwm2
//   bit 7:0: pwm1
#define CMD_PWM1_MASK 0x000000FF
#define CMD_PWM2_MASK 0x0000FF00
#define CMD_DIR1_MASK 0x00010000
#define CMD_DIR2_MASK 0x00020000
#define CMD_ENL_MASK  0x00040000
#define CMD_REQB_MASK 0x00080000
#define CMD_REQS_MASK 0x00100000
#define CMD_REQA_MASK 0x00200000
#define CMD_REQL_MASK 0x00400000
#define CMD_SHDN_MASK 0x00800000
#define CMD_REQC_MASK 0x01000000
#define CMD_ACCUM_MASK (CMD_REQB_MASK | CMD_REQS_MASK | CMD_REQA_MASK | CMD_REQL_MASK | CMD_SHDN_MASK | CMD_REQC_MASK)
#define CMD_MOTOR_MASK (CMD_PWM1_MASK | CMD_PWM2_MASK | CMD_DIR1_MASK | CMD_DIR2_MASK)


// Globals
char socketRxData[MAX_CMD_CHARS];
int socketRxPushI = 0;
int socketRxPopI = 0;
char commandData[32];
int serialFd;



static int OpenSerialPort(const char *deviceFilePath)
{
    int fd = -1;
    struct termios options;

    // Attempt to open
    fd = open(deviceFilePath, O_RDWR | O_NOCTTY | O_NONBLOCK);
    if (fd == -1)
    {
        perror("Error opening serial port");
        close(fd);
        return(-1);
    }

    // Configure options
    options.c_cflag = CS8 | CLOCAL | CREAD;
    options.c_iflag = IGNCR;
    options.c_oflag = 0;
    options.c_lflag = 0;
    tcsetattr(fd,TCSANOW,&options);

    // success
    return fd;
}


void CloseSerialPort(int fd)
{
    // Block until all written output has been sent from the device.
    if (tcdrain(fd) == -1)
    {
        perror("Error waiting for drain");
    }   

    close(fd);
}


static int OpenSocket(int port)
{
    int socket_desc;
    struct sockaddr_in server;

    // Create socket
    socket_desc = socket(AF_INET , SOCK_STREAM , 0);
    if (socket_desc == -1)
    {
        perror("Could not create socket");
        return -1;
    }
     
    // Prepare the sockaddr_in structure
    server.sin_family = AF_INET;
    server.sin_addr.s_addr = INADDR_ANY;
    server.sin_port = htons(port);
     
    // Bind
    if( bind(socket_desc,(struct sockaddr *)&server , sizeof(server)) < 0)
    {
        //print the error message
        perror("Bind failed");
        return -1;
    }
     
    // Listen (??? used to be 3)
    listen(socket_desc, 1);

    return socket_desc;
}

    
void SendCmd(int fd, char* cmdP) {
    write(fd, cmdP, strlen(cmdP));
    write(fd, "\r", 1);
    if (tcdrain(fd) == -1)
    {
        perror("Error waiting for drain after sending command");
    }   
}


// Process an incoming message dealing with the fact that we may receive multiple
// command words in the same recv or we may only receive a partial word.  
int ProcessClientMsg(char* msg, uint32_t* retVal) {
    char curCmdS[16]; // Large enough for our command word string + null
    int curCmdI;
    int i = 0;
    int gotCommand = 0;
    uint32_t lastVal;
    uint32_t accumVal = 0;

    // Copy the current data into our receive buffer
    while (*(msg + i) != 0) {
//printf("copy %d %c\n", i, *(msg + i));
        socketRxData[socketRxPushI] = *(msg + i);
        if (++socketRxPushI >= MAX_CMD_CHARS) socketRxPushI = 0;
        i++;
    }

    // Scan through our receive buffer looking for complete command words (bracketed
    // by 'S' and 'E'
    i = socketRxPopI;
    while (i != socketRxPushI) {
//printf("Process %d %c\n", i, socketRxData[i]);
        if (socketRxData[i] == 'S') {
            // Reset the curCmdI index 
            curCmdI = 0;
            memset(curCmdS, '\0', sizeof(curCmdS));
        } else if (socketRxData[i] == 'E') {
            // Process a complete command word
            if (curCmdI != 0) {
                lastVal = atoi(curCmdS);
//printf("  0x%8x\n", lastVal);
                // Modify accumVal with latest light enable
                if (lastVal & CMD_ENL_MASK) {
                    accumVal |= CMD_ENL_MASK;
                } else {
                    accumVal &= ~CMD_ENL_MASK;
                }

                // Accumulate requests for info
                accumVal |= (lastVal & CMD_ACCUM_MASK);

                // Note success
                gotCommand = 1;
            }

            // Update pop index to last command processed
            socketRxPopI = i;
        } else {
            // Store command data
            if (curCmdI < sizeof(curCmdS)-1) {
                curCmdS[curCmdI++] = socketRxData[i];
            }
        }
        if (++i >= MAX_CMD_CHARS) i = 0;
    }

    // Update command word with all accumulated info requests and final motor command
    if (gotCommand) {
        *retVal = accumVal | (lastVal & CMD_MOTOR_MASK);
    }

    return gotCommand;
}


void ProcessMotor(uint32_t cmd) {
    static uint8_t pwm1 = 0;
    static uint8_t pwm2 = 0;
    static int dir1 = 0;
    static int dir2 = 0;
    uint8_t newPwm1, newPwm2;
    int newDir1, newDir2;

    newPwm1 = cmd & 0xFF;
    newPwm2 = (cmd >> 8) & 0xFF;
    newDir1 = (cmd & CMD_DIR1_MASK) ? 1 : 0;
    newDir2 = (cmd & CMD_DIR2_MASK) ? 1 : 0;

    if ((newPwm1 != pwm1) || (newDir1 != dir1) || (newPwm2 != pwm2) || (newDir2 != dir2)) {
        pwm1 = newPwm1;
        pwm2 = newPwm2;
        dir1 = newDir1;
        dir2 = newDir2;

        sprintf(commandData, "P1=%0d\r", pwm1);
        SendCmd(serialFd, commandData);
        sprintf(commandData, "P2=%0d\r", pwm2);
        SendCmd(serialFd, commandData);
        if (dir1 == 0) {
            digitalWrite(0, LOW);
        } else {
            digitalWrite(0, HIGH);
        }
        if (dir2 == 0) {
            digitalWrite(1, LOW);
        } else {
            digitalWrite(1, HIGH);
        }
    }
}


void ProcessLight(uint32_t cmd) {
    static int lightEn = 0;
    int newEn = (cmd & CMD_ENL_MASK) ? 1 : 0;

    if (newEn != lightEn) {
        lightEn = newEn;
        sprintf(commandData, "U1=%0d\r", lightEn);
        SendCmd(serialFd, commandData);
    }
}


void ProcessQuery(uint32_t cmd) {
    if (cmd & CMD_REQB_MASK) {
        SendCmd(serialFd, "B");
    }
    if (cmd & CMD_REQS_MASK) {
        SendCmd(serialFd, "S");
    }
    if (cmd & CMD_REQA_MASK) {
        SendCmd(serialFd, "A1");
    }
    if (cmd & CMD_REQC_MASK) {
        SendCmd(serialFd, "A2");
    }
    if (cmd & CMD_REQL_MASK) {
        SendCmd(serialFd, "U1");
    }
}


void ProcessShutdown(uint32_t cmd) {
    if (cmd & CMD_SHDN_MASK) {
        puts("shutdown now");
        SendCmd(serialFd, "O=30");
        system("shutdown now&");
    }
}



int main(int argc, char** argv) {
    char *optValue = NULL;
    char serName[MAX_SER_NAME_CHARS];
    char clientMsg[MAX_CMD_CHARS/4 + 1];
    char deviceMsg[MAX_RSP_CHARS + 1];
    int c;
    int socketFd, clientFd;
    int read_size;
    int clientConnected;
    struct sockaddr_in client;
    uint32_t inVal;

    // setup
    memset(serName, '\0', sizeof(serName));
    strcpy(serName, "/dev/ttyACM0");

    // process command line arguments
    while ((c = getopt(argc, argv, "p:")) != -1) {
        switch(c) {
            case 'p':
                memset(serName, '\0', sizeof(serName));
                strncpy(serName, optarg, MAX_SER_NAME_CHARS-1);
                break;
            default:
              abort();
        }
    }

    // Try to open the serial port
    if ((serialFd = OpenSerialPort(serName)) == -1) {
        return(-1);
    }

    // Try to open the socket
    if ((socketFd = OpenSocket(TCP_PORT)) == -1) {
        return(-1);
    }

    // Setup wiring
    wiringPiSetup () ;
    pinMode (0, OUTPUT) ;
    pinMode (1, OUTPUT) ;

    // Configure Analog input 1 to use a 4.096 volt Vref (15 cm min)
    SendCmd(serialFd, "C4=3");
    // Configure Analog input 1 to use a 2.048 volt Vref (30 cm min)
    //SendCmd(serialFd, "C4=2");
    // Configure Analog input 2 to use 2.048 volt Vref (2 A max)
    SendCmd(serialFd, "C5=2");

    // Configure the PWM to fast mode for best motor control
    SendCmd(serialFd, "C6=0");
     
    // Accept incoming connections - first time through this loop, we block until connected
    puts("Waiting for incoming connections...");
    c = sizeof(struct sockaddr_in);
    clientConnected = 0;
    while (1) {
        if ((clientFd = accept(socketFd, (struct sockaddr *)&client, (socklen_t*)&c)) < 0) {
            perror("Accept failed");
            return(-1);
        }
        clientConnected = 1;
        puts("Connection accepted");

        // Convert to non-blocking
        fcntl(clientFd, F_SETFL, O_NONBLOCK);

        // Process messages from client until it disconnects
        while (clientConnected) {
            // Look for incoming commands to process
            memset(clientMsg, '\0', sizeof(clientMsg));
            read_size = recv(clientFd, clientMsg, sizeof(clientMsg)-1, 0);
            if (read_size <= 0) {
                if (read_size == 0) {
                    clientConnected = 0;
                    puts("Client disconnect");
                }
            } else {
                if (ProcessClientMsg(clientMsg, &inVal)) {
                    ProcessMotor(inVal);
                    ProcessLight(inVal);
                    ProcessQuery(inVal);
                    ProcessShutdown(inVal);
                }
            }

            // Look for device serial responses to send back
            memset(deviceMsg, '\0', sizeof(deviceMsg));
            read_size = read(serialFd, deviceMsg, MAX_RSP_CHARS);
            if (read_size > 0) {
                (void) send(clientFd, deviceMsg, read_size, 0);
            }

            // Be a little nice...
            (void) usleep((unsigned int) 20000);
        }

        // Be a little nice...
        (void) usleep((unsigned int) 20000);
    } 

    // Successfully done
    CloseSerialPort(serialFd);
    return(0);
}

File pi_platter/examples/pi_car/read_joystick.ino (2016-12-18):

// Joystick code with serial output
//   - x, y pot (on A1, A0)
//   - button (on D9)
//
// Output format S<B>,<X>,<Y>E when something changed
//   <B> - 0/1 button
//   <X>,<Y> - 0-1023 pot position (center @ 512)
//
#define NUM_SAMPLES     5

#define HYSTERESIS      3
#define CENTER_DELTA    48

#define ST_IDLE         0
#define ST_ACTIVE       1
#define ST_CAL          2



uint8_t myState;

uint16_t xArray[NUM_SAMPLES];
uint16_t yArray[NUM_SAMPLES];
int pushI;
uint8_t tickCount;
uint16_t stateCount;

uint16_t xCenter;
uint16_t yCenter;

uint16_t xPrev;
uint16_t yPrev;
int bPrev;

int debug = 0;



void setup() {
  pinMode(9, INPUT_PULLUP);
  pinMode(13, OUTPUT);
  Serial.begin(115200);

  // Look for special entry into debug mode
  if (digitalRead(9) == 0) {
    debug = 1;
    digitalWrite(13, HIGH);
    while (digitalRead(9) == 0) {
      delay(10);
    }
    digitalWrite(13, LOW);
    delay(1000);
  }
  
  for (int i=0; i<NUM_SAMPLES; i++) {
    xArray[i] = GetXAdc();
    yArray[i] = GetYAdc();
    delay(10);
  }
  xCenter = ComputeAvg(xArray);
  yCenter = ComputeAvg(yArray);
  if (debug) {
    Serial.print(F("Center = "));
    Serial.print(xCenter);
    Serial.print(F(" "));
    Serial.println(yCenter);
  }

  xPrev = 512;
  yPrev = 512;
  bPrev = 0;

  myState = ST_IDLE;
  pushI = 0;
  tickCount = 0;
  stateCount = 0;

  // Send an initial value
  SendData(0, 512, 512);
}


void loop() {
  int bCur;
  uint16_t xRaw;
  uint16_t yRaw;
  uint16_t xCur;
  uint16_t yCur;

  // Update values
  xArray[pushI] = GetXAdc();
  yArray[pushI] = GetYAdc();
  if (++pushI == NUM_SAMPLES) pushI=0;

  // Evaluate periodically (50 mSec - 20/sec)
  if (++tickCount == 5) {
    tickCount = 0;
    bCur = (digitalRead(9) == 0);

    xRaw = ComputeAvg(xArray);
    yRaw = ComputeAvg(yArray);
    xCur = CalibrateValue(xRaw, xCenter);
    yCur = CalibrateValue(yRaw, yCenter);

    switch (myState) {
      case ST_IDLE:
        // Look for button or change greater than hysteresis limits to move to active
        if ((bCur != bPrev) || ValBeyondHysteresis(xCur, yCur)) {
          stateCount = 0;
          myState = ST_ACTIVE;
          SendData(bCur, xCur, yCur);
          bPrev = bCur;
          xPrev = xCur;
          yPrev = yCur;
          if (debug) {
            Serial.println(F("IDLE->ACTIVE"));
          }
        } else {
          // Self-cal every once-in-a-while while we're idle
          if (++stateCount == 40) {
            digitalWrite(13, HIGH);
            stateCount = 0;
            myState = ST_CAL;
            xCenter = xRaw;
            yCenter = yRaw;
            if (debug) {
              Serial.print(F("IDLE->CAL : Center = "));
              Serial.print(xCenter);
              Serial.print(F(" "));
              Serial.println(yCenter);
            }
          }
        }
        break;
        
      case ST_ACTIVE:
        // Sensitive to any change while active
        if ((bCur != bPrev) || (xCur != xPrev) || (yCur != yPrev)) {
          SendData(bCur, xCur, yCur);
          bPrev = bCur;
          xPrev = xCur;
          yPrev = yCur;
        }
        
        // Look for remaining near center for a second to go back to idle
        if (ValNearCenter(xCur, yCur)) {
          if (++stateCount == 20) {
            stateCount = 0;
            myState = ST_IDLE;
            if (debug) {
              Serial.println(F("ACTIVE->IDLE"));
            }
          }
        } else {
          stateCount = 0;
          if (debug) {
            Serial.print(F("Val not near center : val, center = "));
            Serial.print(xCur);
            Serial.print(F(" "));
            Serial.print(yCur);
            Serial.print(F(", "));
            Serial.print(xCenter);
            Serial.print(F(" "));
            Serial.println(yCenter);
          }
        }
        break;
        
      case ST_CAL:
          digitalWrite(13, LOW);
          myState = ST_IDLE;
          if (debug) {
              Serial.println(F("CAL->IDLE"));
            }
        break;
        
      default:
        myState = ST_IDLE;
    }

    
  }
  delay(10);
}


uint16_t GetYAdc() {
  return (uint16_t) analogRead(A0);
}


uint16_t GetXAdc() {
  return (uint16_t) (1023 - analogRead(A1));
}


uint16_t ComputeAvg(uint16_t* sP) {
  uint16_t sum = 0;
  uint16_t avg;

  for (uint8_t i=0; i<NUM_SAMPLES; i++) {
    sum += *(sP + i);
  }

  avg = sum / NUM_SAMPLES;
  if ((sum % NUM_SAMPLES) >= (NUM_SAMPLES/2)) {
    avg++;
  }

  if (avg > 1023) avg = 1023;

  return avg;
}


uint16_t CalibrateValue(uint16_t v, uint16_t c) {
  if (v < c) {
    // map v in (0, c) to (0, 511) : v/c * 511
    return (uint16_t) map(v, 0, c, 0, 511);
  } else {
    // map v in (c, 1023) to (512, 1023)
    return (uint16_t) map(v, c, 1023, 512, 1023);
  }
}


int ValBeyondHysteresis(uint16_t x, uint16_t y) {
  return ((x < (xPrev - HYSTERESIS)) || (x > (xPrev + HYSTERESIS)) ||
          (y < (yPrev - HYSTERESIS)) || (y > (yPrev + HYSTERESIS)));
}


int ValNearCenter(uint16_t x, uint16_t y) {
  return ((((x >= (xCenter - CENTER_DELTA)) && (x <= (xCenter + CENTER_DELTA))) ||
           ((x >= (512 - CENTER_DELTA)) && (x <= (512 + CENTER_DELTA)))) &&
          (((y >= (yCenter - CENTER_DELTA)) && (y <= (yCenter + CENTER_DELTA))) ||
           ((y >= (512 - CENTER_DELTA)) && (y <= (512 + CENTER_DELTA)))));
}


void SendData(int b, uint16_t x, uint16_t y) {
  if (b) {
    Serial.print(F("S1,"));
  } else {
    Serial.print(F("S0,"));
  }
  Serial.print(x);
  Serial.print(F(","));
  Serial.print(y);
  Serial.println(F("E"));
}

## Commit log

2016-12-14 Documentation Initial check-in
    Schematic and quick instructions initial check-in
2017-01-03 Removed cut&paste extraneous text
2017-01-18 Add info about power down script
2019-10-19 Corrected battery description
2022-08-28 Big update (include Porta-Pi)
    [mount_plate.scad, mount_plate.stl]
